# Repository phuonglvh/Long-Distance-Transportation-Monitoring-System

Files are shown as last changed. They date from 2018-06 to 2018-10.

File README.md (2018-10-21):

# **Long-Distance-Transportation-Monitoring-System**
In this project, we did make a Tracker and a real system that has been on the markets. This tracker is specially designed for portable and low power so that it can get along with the carriers for a months.

## Description
This system is made up of 2 main parts, a web server and trackers. Web server is powered by SailsJS MVC and MySQL database to collect humidity, temperature and coordinates of trackers. It also provides web service to users to monitor their packages (containers, ...). Front-end is designed to monitor their package via grap, google maps and some warning protection.

## System model
<p align="center">
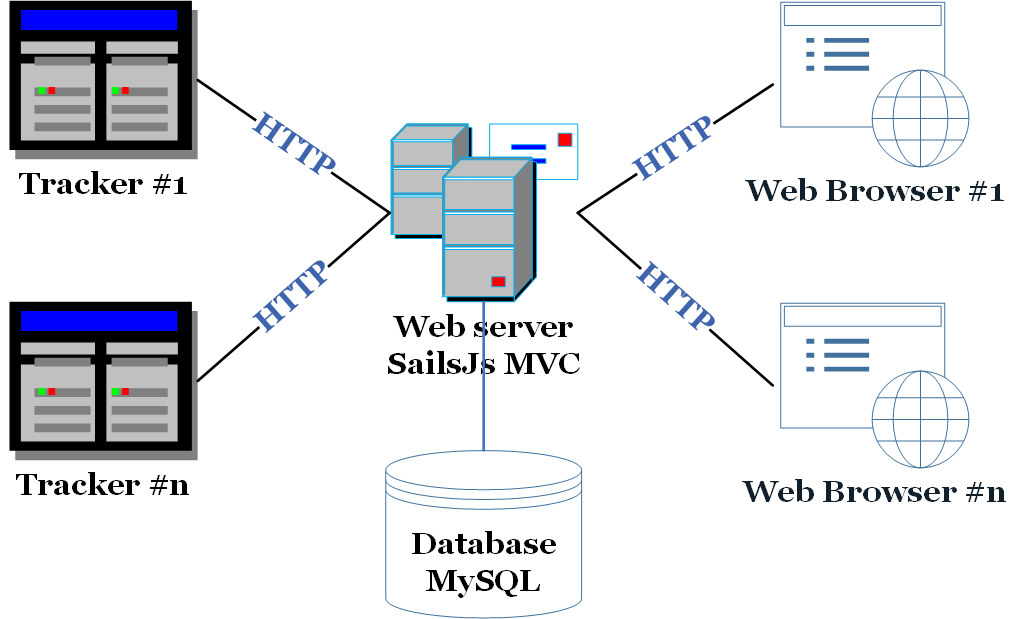
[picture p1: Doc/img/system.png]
System model
  
</p>

## Getting Started
These instructions will get you a copy of the project up and you can develop it for further purposes. See deployment for notes on how to deploy the project on a live system.

### Prerequisites
What things you need to have before operating the whole system
```
A server powered by Linux can run nodejs environment.
MySQL is installed on that server.
SailsJs application
```

### Installing
What you need to install
```
Ubuntu 16.04 or higher or other Linux Distros
nodejs: https://nodejs.org/en/
Sailsjs: https://sailsjs.com/get-started
mysql (I use Ubuntu): sudo apt-get install mysql-server mysql-client
```	

## Hierachy of Project
There are four main folder in this project:  **Web Server**,  **Tracker**,  **Doc**.

**Document** contains such files as *.pdf*, *.docx*, etc describing the whole of our project.
**Web Server** stores code that executed on a Linux Distro based PC.
**Tracker** contains code run on MC60 Kit.

## Deployment
At first, you should setup config/local.js. Add your MySQL information in it.
Secondly, navigate to Web Server root folder and hit ```./start.sh```.
Finally, power on your Kit

## Some results
<p align="center">
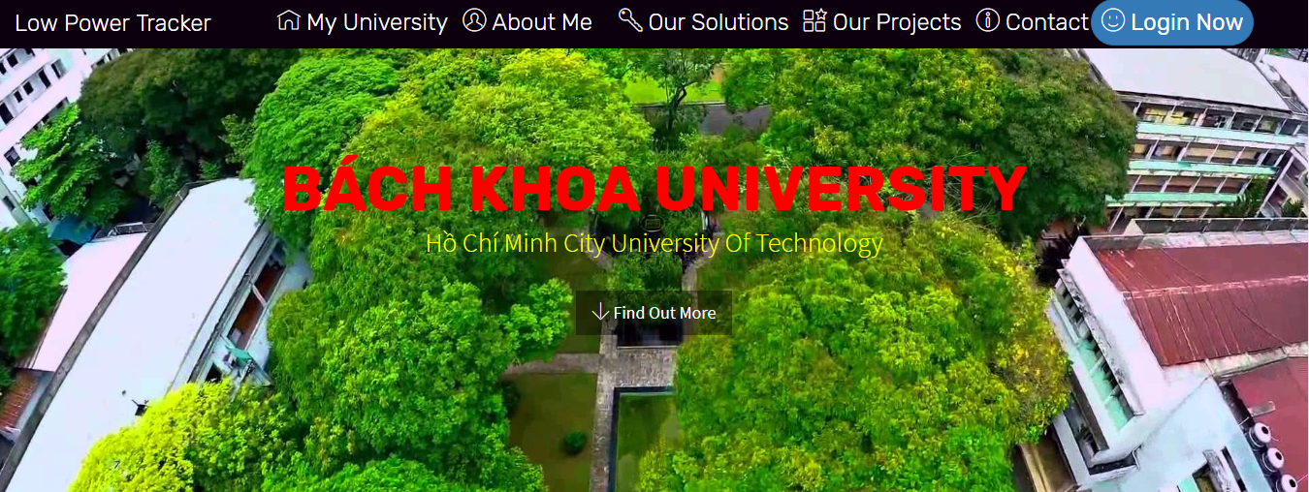
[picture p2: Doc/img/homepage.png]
homepage
  
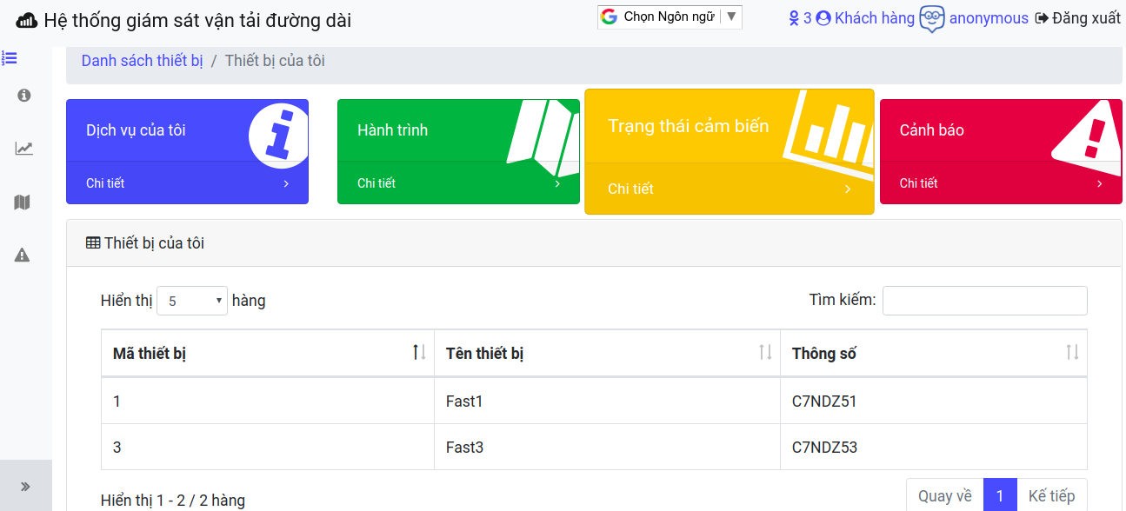
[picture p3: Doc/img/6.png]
Dashboard
  
</p>

<p align="center">
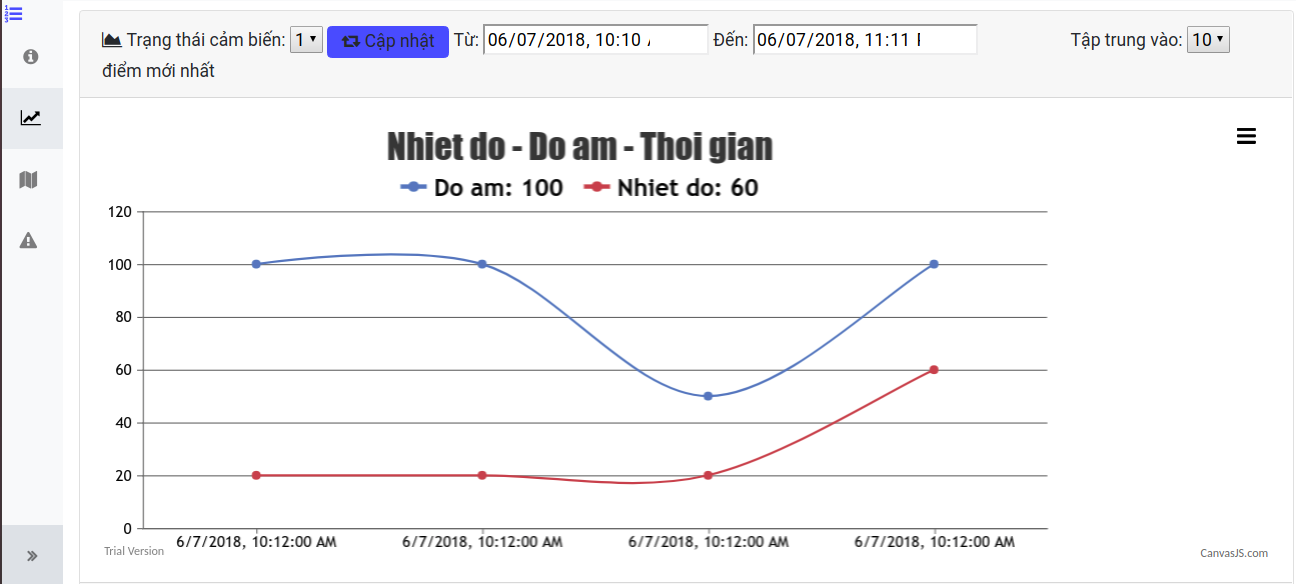
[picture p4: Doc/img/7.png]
Graph
  
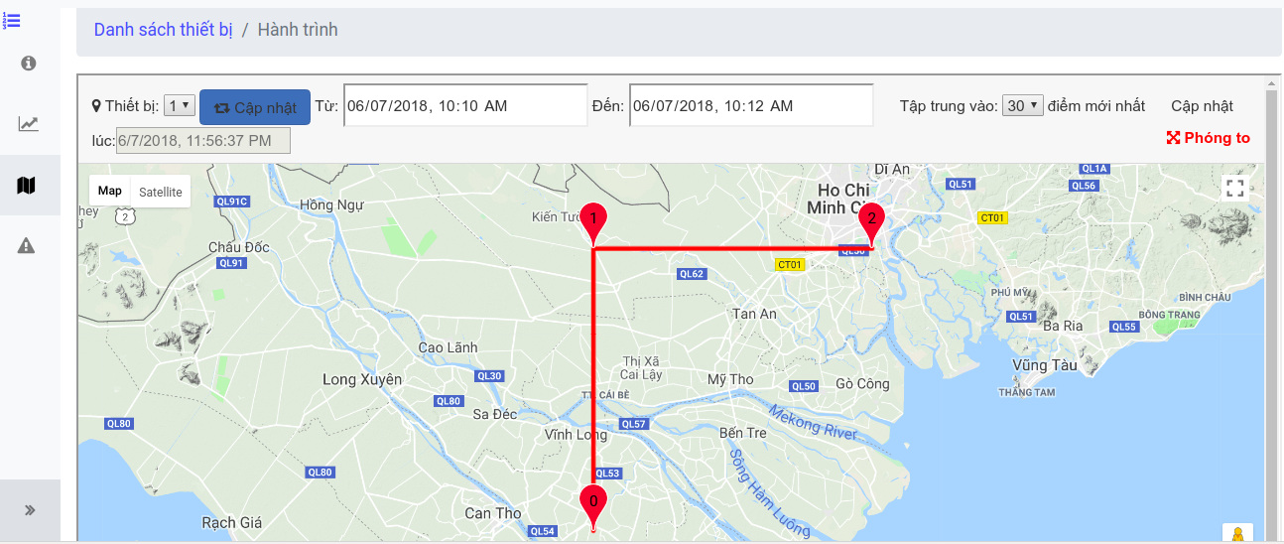
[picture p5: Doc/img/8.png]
Map
  
</p>

<p align="center">
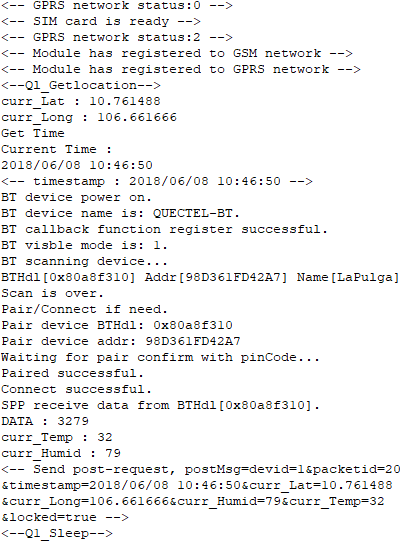
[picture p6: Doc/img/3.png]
MC60
  
</p>

<p align="center">
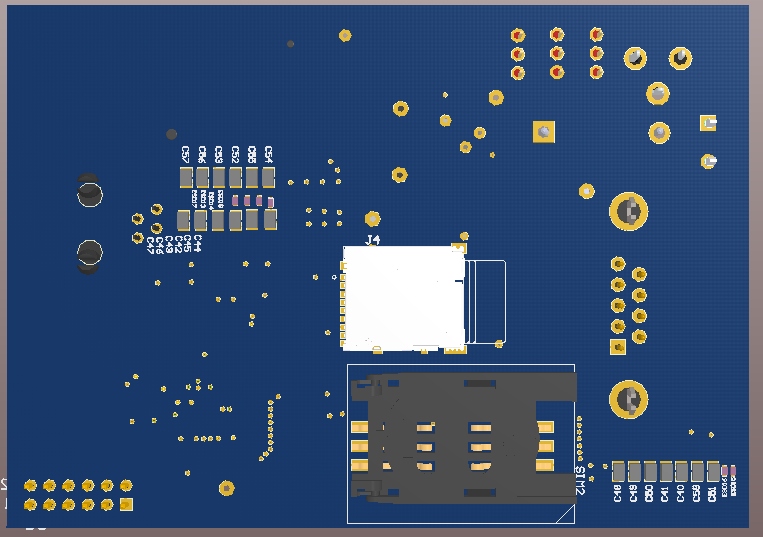
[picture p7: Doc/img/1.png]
top
  
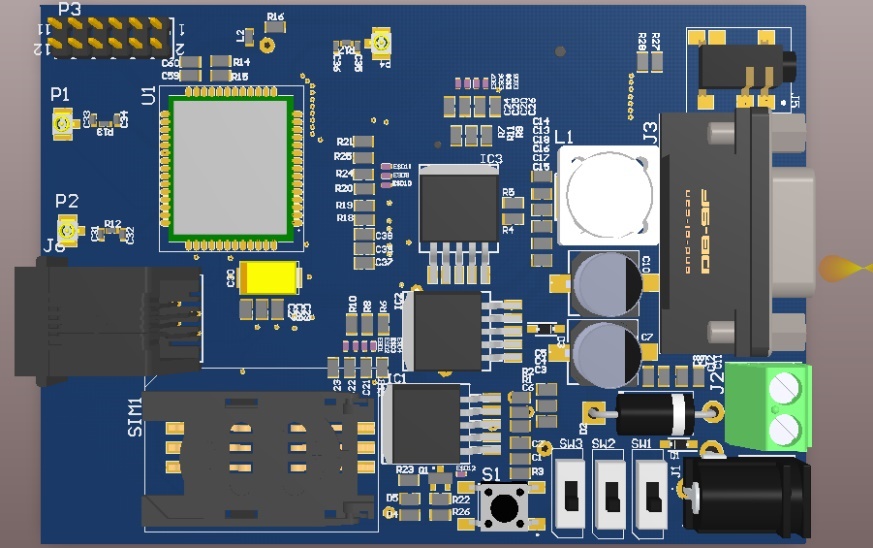
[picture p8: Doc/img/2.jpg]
bottom
  
</p>

## Team members

* **Phuong Le Van Hoang** - **Leader**, *Operating Platform Development*, *Web Server*
* **Nhan Huu Nguyen** - *Firmware Development*
* **Hieu Trung Nguyen** - *Hardware Design*

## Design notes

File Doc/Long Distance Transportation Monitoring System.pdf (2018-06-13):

### ĐẠI HỌC QUỐC GIA TP.HỒ CHÍ MINH TRƯỜNG ĐẠI HỌC BÁCH KHOA KHOA ĐIỆN – ĐIỆN TỬ BỘ MÔN ĐIỆN TỬ

-------------o0o-------------

## ĐỒ ÁN MÔN HỌC

## HỆ THỐNG GIÁM SÁT VẬN TẢI ĐƯỜNG DÀI

GVHD: TS. Trương Quang Vinh
SVTH | MSSV
Lê Văn Hoàng Phương 1512579
Nguyễn Hữu Nhân | 1512263
Nguyễn Trung Hiếu | 1511027

TP. HỒ CHÍ MINH, THÁNG 6 NĂM 2018

Lời cảm ơn | GVHD: TS. Trương Quang Vinh

i

## LỜI CẢM ƠN

Lời đầu tiên, chúng em xin gửi lời cảm ơn tới tiến sĩ Trương Quang Vinh đã quan tâm, hướng

dẫn, cung cấp thông tin và giúp nhóm em trong quá trình hoàn thành đồ án này. Hơn nữa em

xin cảm ơn tất cả thầy cô trường Đại học Bách Khoa TP Hồ Chí Minh đã giúp đỡ, truyền đạt

những kiến thức chuyên ngành quý giá giúp em hoàn thành đồ án này. Và cuối cùng, em xin

chân thành cảm ơn gia đình và bạn bè đã động viên khích lệ nhóm em trong quá trình học tập và hoàn thành đồ án.

Do thời gian thực hiện không nhiều nên đồ án không tránh khỏi những sai sót. Em rất mong

nhận được lời khuyên và sự đóng góp ý kiến của các thầy cô giáo và các bạn quan tâm đến đề

tài này để em có thể bổ sung và tiếp tục phát triển đề tài trong thời gian tới.

Em xin chân thành cảm ơn!

Tp. Hồ Chí Minh, ngày 6 tháng 6 năm 2018.

Sinh viên

Đồ án môn học | GVHD: TS. Trương Quang Vinh

ii

## TÓM TẮT ĐỒ ÁN

Đồ án này trình bày về thiết kế hệ thống giám sát vận tải đường dài. Đề tài chủ yếu tập trung vào

thiết kế sơ bộ một hệ thống gồm 2 thành phần quan trọng là máy chủ dịch vụ web và thiết bị thu

thập dữ liệu, đề xuất giải pháp tối ưu phần cứng. Dịch vụ web được thiết kế theo mô hình MVC với

framework chính là SailsJS, một framework được xây dựng trên nền tảng nodejs và được tính hợp

rất nhiều tính năng tiện lợi. Phần cứng là thiết bị thu thập nhiệt độ, độ ẩm, trạng khái khóa, GPS mà

trung tâm điều khiển là Quectel MC60, với giá thành vừa phải, đủ ngoại vi cần thiết và đầy đủ giao

thức mạng. Phần cứng được thiết kế và lập trình tối ưu nhằm tăng hiệu xuất và tiết kiệm năng lượng.

Giao tiếp người dùng (GUI) được xây dựng chính trên nền tảng web để người dùng có thể giám sát

gói hàng, thiết bị vận tải của mình một cách dễ dàng.

iii

## MỤC LỤC

1. GIỚI THIỆU _________________________________________________________________________________________________________ 1
1.1. Tổng quan ____________________________________________________________________________________________________ 1
1.1.1. Tình hình nghiên cứu trong nước___________________________________________________________________ 1
1.1.2. Tình hình nghiên cứu ngoài nước __________________________________________________________________ 1
1.2. Nhiệm vụ đề tài ______________________________________________________________________________________________ 2
1.3. Phân chia công việc trong nhóm __________________________________________________________________________ 3
2. LÝ THUYẾT _________________________________________________________________________________________________________ 4
2.1. Công nghệ GPS _______________________________________________________________________________________________ 4
2.2. Công nghệ Bluetooth ________________________________________________________________________________________ 4
2.3. Dịch vụ GPRS _________________________________________________________________________________________________ 4
3. TỔNG QUÁT HỆ THỐNG___________________________________________________________________________________________ 5
3.1. Mô tả hệ thống _______________________________________________________________________________________________ 5
4. THIẾT KẾ VÀ THỰC HIỆN PHẦN CỨNG _________________________________________________________________________ 7
4.1. Yêu cầu thiết kế ______________________________________________________________________________________________ 7
4.2. Phân tích thiết kế ____________________________________________________________________________________________ 7
4.3. Sơ đồ khối tổng quát ________________________________________________________________________________________ 8
4.3.1. MC60_____________________________________________________________________________________________________ 8
4.3.2. Khối cấp nguồn_________________________________________________________________________________________ 9
4.3.3. Khối giao tiếp Audio__________________________________________________________________________________10
4.3.4. Khối Giao tiếp thẻ SIM _______________________________________________________________________________11
4.3.5. Khối Antenna__________________________________________________________________________________________11
4.3.6. Khối giao tiếp UART__________________________________________________________________________________12
4.3.7. Giao tiếp với thẻ SD __________________________________________________________________________________12
4.3.8. POWER LED và NETLIGHT LED ____________________________________________________________________13
4.3.9. Nút nhấn PWRKEY____________________________________________________________________________________13
4.3.10. Khối cảm biến _________________________________________________________________________________________14
4.4. Tính toán và vẽ sơ đồ mạch chi tiết______________________________________________________________________17
4.4.1. MC60-OpenCPU _______________________________________________________________________________________17

iv

4.4.2. Khối cấp nguồn________________________________________________________________________________________18
4.4.3. Khối giao tiếp Audio__________________________________________________________________________________21
4.4.4. Khối giao tiếp thẻ SIM________________________________________________________________________________22
4.4.5. Khối antenna __________________________________________________________________________________________23
4.4.6. Giao tiếp UART ________________________________________________________________________________________27
4.4.7. Giao tiếp với thẻ SD __________________________________________________________________________________28
4.4.8. POWER LED và NETLIGHT LED, PWRKEY Button_______________________________________________29
5. THIẾT KẾ VÀ THỰC HIỆN PHẦN MỀM _________________________________________________________________________31
5.1. Phần mềm thiết bị giám sát (Tracker) __________________________________________________________________31
5.1.1. Phân tích _______________________________________________________________________________________________31
5.1.2. Yêu cầu đặt ra cho phần mềm_______________________________________________________________________31
5.1.3. Cấu trúc chương trình _______________________________________________________________________________32
5.1.4. Lưu đồ giải thuật tổng quát _________________________________________________________________________32
5.1.5. Lưu đồ giải thuật chi tiết ____________________________________________________________________________33
5.2. Phần mềm web server _____________________________________________________________________________________38
5.2.1. Yêu cầu đặt ra _________________________________________________________________________________________38
5.2.2. Phân tích _______________________________________________________________________________________________38
5.2.3. Thiết kế web server __________________________________________________________________________________39
6. KẾT QUẢ THỰC HIỆN ____________________________________________________________________________________________44
6.1. Phần cứng ___________________________________________________________________________________________________44
6.1.1. 3D _______________________________________________________________________________________________________44
6.1.2. LAYOUT ________________________________________________________________________________________________45
6.2. Thiết bị giám sát ____________________________________________________________________________________________46
6.2.1. Thử nghiệm phần mềm giám sát trên KIT MC60 và KIT TM4C123GH6PM __________________46
6.3. Máy chủ dịch vụ web _______________________________________________________________________________________51
6.3.1. Frontend _______________________________________________________________________________________________51
6.4. Đánh giá kết quả____________________________________________________________________________________________57
6.4.1. Phần cứng______________________________________________________________________________________________57
6.4.2. Đánh giá tổng quát kết quả phần cứng ____________________________________________________________59

v

6.4.3. Thiết bị giám sát ______________________________________________________________________________________59
6.4.4. Máy chủ web___________________________________________________________________________________________59
6.4.5. Làm việc nhóm ________________________________________________________________________________________60
7. KẾT LUẬN VÀ HƯỚNG PHÁT TRIỂN ___________________________________________________________________________61
7.1. Kết luận ______________________________________________________________________________________________________61
7.2. Hướng phát triển ___________________________________________________________________________________________61
8. TÀI LIỆU THAM KHẢO ___________________________________________________________________________________________62
9. PHỤ LỤC____________________________________________________________________________________________________________63
9.1. Code web server và thiết bị giám sát ____________________________________________________________________63
9.2. Danh sách linh kiện trong bản vẽ ________________________________________________________________________63

vi

## DANH SÁCH HÌNH MINH HỌA

HÌNH 3.1.1 SƠ ĐỒ KHỐI TỔNG QUÁT HỆ THỐNG ___________________________________________________________________ 5

HÌNH 3.1.2 SƠ ĐỒ KHỐI THIẾT BỊ GIÁM SÁT ________________________________________________________________________ 6 HÌNH 4.3.1 SƠ ĐỒ KHỐI TỔNG QUÁT PHẦN CỨNG _________________________________________________________________ 8

HÌNH 4.3.2 VI ĐIỀU KHIỂN MC-60_____________________________________________________________________________________ 9

HÌNH 4.3.3 SƠ ĐỒ KHỐI CẤP NGUỒN _________________________________________________________________________________ 9

HÌNH 4.3.4 SƠ ĐỒ KHỐI AUDIO_______________________________________________________________________________________10

HÌNH 4.3.5 SƠ ĐỒ KHỐI EARPHONE _________________________________________________________________________________10

HÌNH 4.3.6 SƠ ĐỒ KHỐI MC60-EARPHONE _________________________________________________________________________11

HÌNH 4.3.7 SƠ ĐỒ KHỐI MC60 - SIM _________________________________________________________________________________11

HÌNH 4.3.8 SƠ ĐỒ KHỐI ANTENNA___________________________________________________________________________________11

HÌNH 4.3.9 SƠ ĐỒ KHỐI GIAO TIẾP UART __________________________________________________________________________12

HÌNH 4.3.10 SƠ ĐỒ KHỐI KẾT NỐI MAIN UART – DB9 ____________________________________________________________12

HÌNH 4.3.11 SƠ ĐỒ KHỐI GIAO TIẾP SD CARD _____________________________________________________________________12 HÌNH 4.3.12 THỜI GIAN BẬT MODULE BẰNG PWRKEY___________________________________________________________13

HÌNH 4.3.13 THỜI GIAN TẮT MODULE BẰNG PWRKEY___________________________________________________________14

HÌNH 4.3.14 SƠ ĐỒ KẾT NỐI KHỐI CẢM BIẾN ______________________________________________________________________14

HÌNH 4.3.15 KIT TM4C123 ____________________________________________________________________________________________15 HÌNH 4.3.16 SƠ ĐỒ CHÂN DHT11 ____________________________________________________________________________________16

HÌNH 4.3.17 SƠ ĐỒ CHÂN HC-05 _____________________________________________________________________________________16

HÌNH 4.4.1 SƠ ĐỒ CHÂN MC60 _______________________________________________________________________________________17

HÌNH 4.4.2 SƠ ĐỒ KẾT NỐI MC60 ____________________________________________________________________________________18

HÌNH 4.4.3 ĐẦU VÀO 5V SỬ DỤNG DC JACK 3 CHÂN_______________________________________________________________18

HÌNH 4.4.4 KHỐI CẤP NGUỒN_________________________________________________________________________________________19

HÌNH 4.4.5 LẤY ĐIỆN ÁP TỪ MIC29302 _____________________________________________________________________________19

HÌNH 4.4.6 SƠ ĐỒ VBAT _______________________________________________________________________________________________20

HÌNH 4.4.7 TÍNH ĐỘ RỘNG POWER TRACE _________________________________________________________________________21

HÌNH 4.4.8 MC60 - HANDSET QUA AUDIO CHANNEL 1____________________________________________________________21

HÌNH 4.4.9 MC60 – EARPHONE QUA AUDIO CHANNEL 2 _________________________________________________________22 HÌNH 4.4.10 SƠ ĐỒ MẠCH CHI TIẾT SIM1___________________________________________________________________________22

HÌNH 4.4.11 SƠ ĐỒ MẠCH CHI TIẾT SIM2___________________________________________________________________________23

HÌNH 4.4.12 SƠ ĐỒ MẠCH GSM ANTENNA __________________________________________________________________________24

HÌNH 4.4.13 SƠ ĐỒ MẠCH GNSS ANTENNA _________________________________________________________________________25

HÌNH 4.4.14 SƠ ĐỒ MẠCH GSM ANTENNA __________________________________________________________________________26

HÌNH 4.4.15 THIẾT KẾ RF TRACE 50Ω_______________________________________________________________________________27

HÌNH 4.4.16 SƠ ĐỒ MẠCH CHI TIẾT MAIN UART __________________________________________________________________27

HÌNH 4.4.17 SƠ ĐỒ CHÂN DB9________________________________________________________________________________________28

HÌNH 4.4.18 SƠ ĐỒ MẠCH SD CARD__________________________________________________________________________________29

vii

HÌNH 4.4.19 SƠ ĐỒ MẠCH POWER LED _____________________________________________________________________________29

HÌNH 4.4.20 SƠ ĐỒ MẠCH PWRKEY BUTTON ______________________________________________________________________30

HÌNH 5.1.1 CẤU TRÚC CHƯƠNG TRÌNH GIÁM SÁT RTOS MỘT TASK ___________________________________________32 HÌNH 5.1.2 GIẢI THUẬT TỔNG QUÁT CHƯƠNG TRÌNH GIÁM SÁT_______________________________________________32

HÌNH 5.1.3 GIẢI THUẬT BOOT SYSTEM _____________________________________________________________________________33

HÌNH 5.1.4 GIẢI THUẬT LOCATION PROGRAM_____________________________________________________________________33 HÌNH 5.1.5 GIẢI THUẬT ĐỌC CẢM BIẾN_____________________________________________________________________________34

HÌNH 5.1.6 GIẢI THUẬT TRUYỀN NHẬN BLUETOOTH(HOST) ___________________________________________________35

HÌNH 5.1.7 GIẢI THUẬT TRUYỀN NHẬN BLUETOOTH (SLAVE) __________________________________________________36

HÌNH 5.1.8 GIẢI THUẬT HTTP POST_________________________________________________________________________________37

HÌNH 5.2.1 MÔ HÌNH MVC VÀ SAILSJS _______________________________________________________________________________39 HÌNH 5.2.2 GIAO DIỆN TRANG CHỦ __________________________________________________________________________________40

HÌNH 5.2.3 GIAO DIỆN QUẢN LÍ CỦA KHÁCH HÀNG _______________________________________________________________40

HÌNH 5.2.4 GIAO DIỆN QUẢN LÍ CỦA QUẢN TRỊ VIÊN _____________________________________________________________40 HÌNH 5.2.5 CẤU TRÚC CSDL VÀ QUAN HỆ GIỮA CÁC TRƯỜNG __________________________________________________41

HÌNH 6.1.1 ẢNH 3D MẶT TRÊN _______________________________________________________________________________________44

HÌNH 6.1.2 ẢNH 3D MẶT DƯỚI CỦA MẠCH _________________________________________________________________________44 HÌNH 6.1.3 ẢNH LAYOUT PHẦN CỨNG ______________________________________________________________________________45

HÌNH 6.2.1 KẾT QUẢ DỮ LIỆU GPS ___________________________________________________________________________________46

HÌNH 6.2.2 KẾT QUẢ DỮ LIỆU THỜI GIAN __________________________________________________________________________46

HÌNH 6.2.3 KẾT QUẢ ĐỌC CẢM BIẾN NHIỆT ĐỘ - ĐỘ ẨM _________________________________________________________47

HÌNH 6.2.4 QUÁ TRÌNH GỬI DỮ LIỆU________________________________________________________________________________48

HÌNH 6.2.5 SERVER ĐÃ NHẬN DỮ LIỆU THÀNH CÔNG ____________________________________________________________48 HÌNH 6.2.6 SERVER TỪ CHỐI LƯU DỮ LIỆU DO PACKET ĐÃ NHẬN TRƯỚC ĐÓ_______________________________49

HÌNH 6.2.7 TRẠNG THÁI CẢM BIẾN TRƯỚC KHI WEB SERVER NHẬN DỮ LIỆU_______________________________49

HÌNH 6.2.8 TRẠNG THÁI CẢM BIẾN SAU KHI SERVER NHẬN DỮ LIỆU__________________________________________49

HÌNH 6.2.9 HÀNH TRÌNH TRƯỚC KHI SERVER NHẬN DỮ LIỆU__________________________________________________50

HÌNH 6.2.10 HÀNH TRÌNH SAU KHI SERVER NHẬN DỮ LIỆU ____________________________________________________50 HÌNH 6.3.1 KẾT QUẢ: TRANG CHỦ ___________________________________________________________________________________51

HÌNH 6.3.2 KẾT QUẢ: GIAO DIỆN QUẢN LÍ THÔNG TIN TÀI KHOẢN ____________________________________________51

HÌNH 6.3.3 KẾT QUẢ: GIAO DIỆN - QTV______________________________________________________________________________51

HÌNH 6.3.4 KẾT QUẢ: QUẢN LÍ DỊCH VỤ - QTV _____________________________________________________________________52

HÌNH 6.3.5 KẾT QUẢ: XEM LỊCH SỬ DV - QTV ______________________________________________________________________52

HÌNH 6.3.6 KẾT QUẢ: TRANG QUẢN LÍ - KH ________________________________________________________________________52

HÌNH 6.3.7 KẾT QUẢ: BẢNG THÔNG TIN DỊCH VỤ CỦA KH _______________________________________________________53

HÌNH 6.3.8 KẾT QUẢ: BẢNG TRẠNG THÁI CẢM BIẾN - KH ________________________________________________________53

HÌNH 6.3.9 KẾT QUẢ: GIÁM SÁT HÀNH TRÌNH - KH _______________________________________________________________53

HÌNH 6.3.10 KẾT QUẢ: NGƯỠNG - KH _______________________________________________________________________________54

HÌNH 6.3.11 GIAO DIỆN CẢNH BÁO -KH _____________________________________________________________________________54

viii

HÌNH 6.3.12 GIAO DIỆN QUẢN LÍ THIẾT VỊ - QTV__________________________________________________________________54

HÌNH 6.3.13 MÀN HÌNH CONSOLE MÁY CHỦ________________________________________________________________________55

HÌNH 6.3.14 THÔNG TIN TRÊN MYSQL ______________________________________________________________________________55 HÌNH 6.3.15 MÔ PHỎNG GỬI DỮ LIỆU SỬ DỤNG POSTMAN APP________________________________________________56 HÌNH 6.3.16 YÊU CẦU TỪ POSTMAN ĐƯỢC GHI LẠI TRÊN CONSOLE___________________________________________56

HÌNH 6.4.1 KHỐI NGUỒN (TOP) ______________________________________________________________________________________57

HÌNH 6.4.2 KHỐI NGUỒN (BOTTOM) ________________________________________________________________________________57

HÌNH 6.4.3 KHỐI ANTENNA(TOP)____________________________________________________________________________________58

HÌNH 6.4.4 KHỐI ANTENNA(BOTTOM)______________________________________________________________________________58

HÌNH 6.4.5 ĐƯỜNG DÂY TRUYỀN SÓNG_____________________________________________________________________________58

ix

## DANH SÁCH BẢNG SỐ LIỆU

BẢNG 1.3.1 PHÂN CHIA CÔNG VIỆC TRONG NHÓM _________________________________________________________________ 3

BẢNG 4.2.1 LỰA CHỌN MCU____________________________________________________________________________________________ 7

BẢNG 4.2.2 LỰA CHỌN ANTENNA _____________________________________________________________________________________ 7 BẢNG 4.3.1 CHỨC NĂNG CÁC KHỐI PHẦN CỨNG____________________________________________________________________ 8

BẢNG 4.4.1 MÔ TẢ CHÂN AUDIO CHANNEL 1_______________________________________________________________________21

BẢNG 4.4.2 MÔ TẢ CHÂN AUDIO JACK_______________________________________________________________________________22

BẢNG 4.4.3 MÔ TẢ CHÂN SIM1 _______________________________________________________________________________________23

BẢNG 4.4.4 MÔ TẢ CHÂN SIM2 _______________________________________________________________________________________23 BẢNG 4.4.5 YÊU CẦU ANTENNA CABLE ______________________________________________________________________________24

BẢNG 4.4.6 YÊU CẦU THÔNG SỐ ANTENNA _________________________________________________________________________24

BẢNG 4.4.7 CÁC DẢI TẦN GSM ________________________________________________________________________________________25

BẢNG 4.4.8 THÔNG SỐ ĐỐI VỚI ANTENNA GPS ____________________________________________________________________25

BẢNG 4.4.9 MÔ TẢ CHÂN CỦA CỔNG DB9 ___________________________________________________________________________28

BẢNG 4.4.10 MÔ TẢ CHÂN CỦA MICRO-SD__________________________________________________________________________29

BẢNG 5.2.1 TÍNH NĂNG CỦA GIAO DIỆN WEB ______________________________________________________________________38 BẢNG 5.2.2 TÍNH NĂNG GIAO TIẾP VỚI TRACKER_________________________________________________________________38

BẢNG 5.2.3 API PHỤC VỤ DỊCH VỤ WEB_____________________________________________________________________________41 BẢNG 5.2.4 API PHỤC VỤ GIAO TIẾP TRACKER ____________________________________________________________________43

BẢNG 5.2.5 CẤU TRÚC GÓI DỮ LIỆU TRACKER GỬI ĐẾN SERVER _______________________________________________43

BẢNG 5.2.6 CẤU TRÚC GÓI JSON SERVER TRẢ LỜI TRACKER NẾU NHẬN THÀNH CÔNG_____________________43 BẢNG 6.2.1 GPS MẪU___________________________________________________________________________________________________46

x

## THUẬT NGỮ/VIẾT TẮT TIẾNG ANH/VIỆT

[1] Web server: máy chủ lưu trữ dữ liệu và cung cấp dịch vụ web.
[2] Tracker: thiết bị giám sát/thiết bị thu thập dữ liệu.
[3] GUI: graphic user interface
[4] Font-end: giao diện người dùng
[5] Back-end: chương trình chạy tại server
[6] API: application programming interface
[7] MC60: Quectel MC60 Ultra-small LCC Quad-band GSM/GPRS/GNSS Module
[8] RTOS: Realtime Operating System
[9] QTV: quản trị viên
[10] KH: khách hàng

1

### 1. GIỚI THIỆU

### 1.1. Tổng quan

Thế kỉ 21 đánh dấu sự phát triển vượt bật của ngành điện tử, bên cạnh các lĩnh vực công nghệ

cao như IC, RFIC, … thì IoT hiện nay trở thành một xu hướng của thế giới.

Sự phát triển của ngành giao thông vận tải và các ngành kinh tế khác liên quan đã đặt ra một

dấu chấm hỏi mới cho lĩnh vực IoT. Vì sao lại như vậy? Khác với ngành vận tải truyền thống,

ngày nay chúng ta đòi hỏi nghiêm ngặt hơn trong việc giám sát hàng hóa của mình. Hơn thế

nữa, việc vận chuyển hàng hóa có thể vượt không gian, thời gian, châu lục, vậy thì việc đảm

bảo chắc chắn rằng hàng hóa của tôi chất lượng còn nguyên vẹn và dịch vụ vẩn chuyển của tôi

là tốt thì việc đòi hỏi các thiết bị hỗ trợ là môt tất yếu. Chính vì lẽ đó mà có lẽ đã từ rất lâu thiết

bị giám sát đã ra đời đóng góp không nhỏ trong việc phát triển thương mại, giao thông vận tải.

Vì thế không khó hiểu khi những thiết bị giám sát như thế đang ngày càng được cải thiện và

nâng cao chất lượng.

### 1.1.1. Tình hình nghiên cứu trong nước

Hiện nay có rất nhiều doanh nghiệp trong nước cho ra đời thiết bị giám sát hành trình, nhiệt độ,

độ ẩm, … Vậy đâu là dòng sản phẩm tốt nhất, hiệu quả nhất, kinh thế và bền bỉ nhất? Đây có lẽ

là một bài toán không có câu trả lời vì công nghệ không có giới hạn.

Các sản phẩm trong nước thường có những tính năng như sau:

- Định vị vị trí
- Giám sát nhiệt độ, độ ẩm
- Bảo vệ khóa
- Chống nước, chống sốc

Tuy nhiên, đa số các sản phẩm thường sử dụng nguồn điện rời, nguồn điện trực tiếp từ động cơ

hoặc nguồn điện sử dụng được trong thời gian ngắn khiến cho sản phẩm còn một số hạn chế

như: không tách rời, vận tải trong thời gian không dài, …

### 1.1.2. Tình hình nghiên cứu ngoài nước

Hiện nay thị trường nước ngoài đã có những sản phẩm rất tuyệt vời, đáp ứng được những khuyết

điểm trên. Tuy nhiên nếu xét khách hàng trong nước, thì những thiết bị như thế có giá rất cao,

dẫn đến là không phải doanh nghiệp hoặc cá nhân nào cũng mua được. Và sẽ như thế nào nếu

như sản phẩm của tôi bị hỏng?

2

### 1.2. Nhiệm vụ đề tài

Sau khi phân tích tình hình nghiên cứu trong và ngoài nước, cũng như thị trường tiêu thụ, nhóm chúng tôi đã đề xuất xây dựng một hệ thống giám sát vận tải đường dài kế thừa đầy đủ các tính

năng cơ bản, nhưng được cải thiện đáng kể chính là: tiết kiệm năng lượng, thời gian sử dụng

lâu cho vận tải đường dài, thiết bị được đóng gói rời, có thể gắn trên gói hàng hóa để đi theo

suốt hành trình mà không phụ thuộc vào phương tiện vận chuyển.

Từ ý tưởng trên, trong đồ án này, chúng tôi cơ bản tiến hành nghiên cứu với những nội dung

sau:

Nội dung 1: Tìm hiểu về framework SailsJs, MVC và MySQL.

Nội dung 2: Thiết kế website dựa trên nền tảng SailsJS. Giao diện thiết kế cho 2 đối tượng:

khách hàng và quản trị viên. Khách hàng có thể quản lí thông tin tài khoản của mình, quản lí

thiết bị đã đăng kí, theo dõi nhiệt độ - độ ẩm qua biểu đồ và định vị trên Google Map, cảnh báo

vượt ngưỡng và mở khóa. Quản trị viên chính là nhà cung cấp dịch vụ (cung cấp thiết bị giám

sát), có thể quản lí được tài khoản khách hàng, quản lí các dịch vụ, xem lịch sử dịch vụ và các

cài đặt liên quan. Thông tin hiển thị trên web có thể được cập nhật thủ công.

Nội dung 3: Tìm hiểu các module cần thiết để đảm bảo có đủ các chức năng: kết nối

GPRS/2G/3G, UART, Bluetooth, khối cấp nguồn, antenna. Nẵm vững kiến thức về phần cứng

đồng thời hiện thực hóa những module trên bằng schematic, layout.

Nội dung 4: Tìm hiểu và lập trình giao tiếp các ngoại vi như Bluetooth, GPS, GPIO và kết nối

mạng GPRS/2G/3G trên KIT MC60. Lập trình giao tiếp với cảm biến nhiệt độ, độ ẩm thông

qua Bluetooth. Hiểu về cấu trúc chương trình thực hiện trên Kit. Gửi được dữ liệu cơ bản gồm

nhiệt độ, độ ẩm, kinh độ, vĩ độ, thời gian, trạng thái khóa đến server.

Nội dung 5: Kết hợp phần mềm giám sát và phần mềm web server để thành một hệ thống hoàn

chỉnh, chạy thử và kiểm tra hệ thống.

3

### 1.3. Phân chia công việc trong nhóm

Bảng 1.3.1 Phân chia công việc trong nhóm

Thành viên | Vai trò | Công việc | Chi tiết công việc
Lê Văn Hoàng Phương | Nhóm trưởng | Web server | -Tìm hiểu về web, SailsJs, framework - Thiết kế giao diện web(frontend) - Thiết kế backend web - Xây dựng web theo mô hình MVC - Giao tiếp giữa server và thiết bị giám sát
Nguyễn Hữu Nhân | Thành viên | Lập trình nhúng | - Tìm hiểu sử dùng Module SIM, AT command - Tìm hiểu giao thức mạng HTTP POST, GET - Tìm hiểu KIT MC60 - Giao tiếp ngoại vị MC60: GPS, Bluetooth - Kết nối đến Web server sử dụng MC60 - Gửi dữ liệu đến web server
Nguyễn Trung Hiếu | Thành viên | Thiết kế phần cứng | - Đề xuất mô hình phần cứng - Tìm hiểu các loại linh kiện và thị trường - Tối ưu phần cứng - Vẽ schematic phần cứng - Vẽ layout phần cứng - Thiết kế đường dây truyền sóng cho antenna

4

### 2. LÝ THUYẾT

### 2.1. Công nghệ GPS

- Hệ thống GPS (Global Positioning System) là hệ thống xác định vị trí toàn cầu dựa trên hệ

thống vệ tinh. GPS sẽ cung cấp thông tin vị trí địa lý và thời gian (UTC) tới tất cả các thiết

bị bắt GPS.

- Module GPS hỗ trợ gói tin chuẩn NMEA. Mặc định module sẽ trả về lần lượt 6 gói tin:

GPRMC, GPVTG, GPGGA, GPGSA, GPGSV, GPGLL với mục đích khác nhau. Tuy nhiên chỉ với gói tin GPRMC đã có đầy đủ thông tin cho ứng dụng. Ta chỉ cần cắt thông tin về

UTC time, latitude, longtitude và date.

### 2.2. Công nghệ Bluetooth

- Bluetooth là một tiêu chuẩn công nghệ không dây mở độc quyền để trao đổi dữ liệu trong

khoảng cách ngắn (sử dụng sóng vô tuyến bước sóng ngắn trong băng tần ISM từ 2400-

2480MHz) từ các thiết bị cố định và di động, tạo mạng lưới khu vực cá nhân với mức độ

bảo mật cao. Bluetooth đã được chuẩn hóa như IEEE802.15.1.

- Bluetooth có thể đạt được tốc độ truyền dữ liệu 1Mb/s. Bluetooth hỗ trợ tốc độ truyền tải

dữ liệu lên tới 720 Kbps trong phạm vi 10 m–100 m. Khác với kết nối hồng ngoại (IrDA),

kết nối Bluetooth là vô hướng và sử dụng giải tần 2,4 GHz.

### 2.3. Dịch vụ GPRS

- GPRS - General Packet Radio Service là một dịch vụ dữ liệu di động truy cập đến GSM

và IS-136 điện thoại người dùng di động.
- GPRS thay thế cho các kết nối có dây, như hệ thống này đã đơn giản hóa truy cập vào các

mạng dữ liệu gói tin như internet. Các nguyên tắc vô tuyến gói tin được sử dụng bởi GPRS

để vận chuyển các gói dữ liệu một cách cấu trúc giữa trạm di động GSM và mạng dữ liệu

gói bên ngoài. Các gói này có thể được chuyển trực tiếp đến các mạng chuyển mạch gói từ

các trạm di động GPRS.

5

### 3. TỔNG QUÁT HỆ THỐNG

### 3.1. Mô tả hệ thống

Hệ thống giám sát vận tải đường dài thực hiện chức năng là giám sát nhiệt độ - độ ẩm, trạng

thái khóa, hành trình thông qua môi trường GSM. Thiết bị giám sát (Tracker) được gắn xuyên

suốt theo thùng hàng/gói hàng vận chuyển, thường xuyên gửi dữ liệu nhiệt độ, độ ẩm, vị trí,

trạng thái khóa đến một máy chủ (Web Server). Người dùng, người đang thuê thiết bị giám sát

này có thể giám sát thùng hàng/gói hàng của mình đang vận chuyển thông qua trình duyệt web

(Web browser) trên máy tính hoặc điện thoai của họ. Người dùng có thể xem nhiệt độ, độ ẩm

thông qua biểu đồ, hành trình của thùng hàng thông qua bản đồ google map. Chức năng cài đặt

ngưỡng nhiệt độ, độ ẩm và cảnh báo được xây dựng nhằm hỗ trợ người dùng kiểm tra cửa đang

mở hay không, nhiệt độ, độ ẩm có nằm trong giới hạn an toàn hay không.

Để thực hiện được những chức năng trên, hệ thống được thiết kế tương ứng với 3 thành phần

chính được thể hiện thông qua hình dưới đây:

Hình 3.1.1 Sơ đồ khối tổng quát hệ thống

- Web server:
- Cung cấp dịch vụ giám sát thông qua website
- Xử lí dữ liệu nhận được từ tracker, lưu vào CSDL và cung cấp dữ liệu cho giao diện ở

người dùng

- Sử dụng mô hình MVC để quản lí xuyên suốt từ CSDL cho đến giao diện

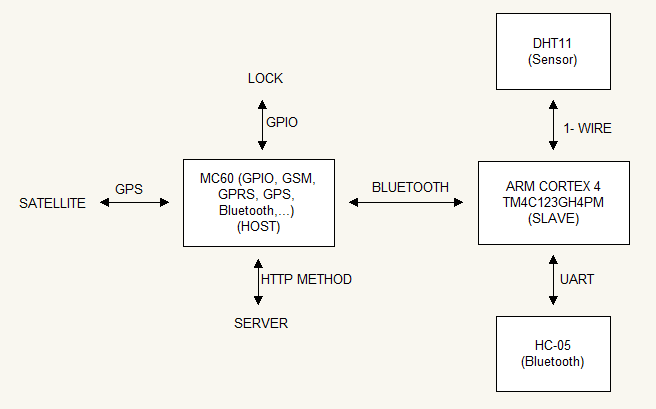
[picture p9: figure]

6

- Tracker (thiết bị giám sát): được gắn trên phương tiện vận tải hàng hóa, gửi dữ liệu nhiệt

độ, độ ẩm, GPS, thời gian, khóa đến máy chủ

Hình 3.1.2 Sơ đồ khối thiết bị giám sát

- Trình duyệt web (Web Browser): hiển thị giao diện web cho người dùng giám sát và quản

lí với các tính năng nêu trên

7

### 4. THIẾT KẾ VÀ THỰC HIỆN PHẦN CỨNG

### 4.1. Yêu cầu thiết kế

- Kích thước nhỏ gọn: 7x10 cm
- Giá thành hợp lý: 1 triệu đồng
- Giảm thiểu tối đa hao phí năng lượng
- Thực hiện truyền nhận đầy đủ các tín hiệu: GSM, GNSS, Bluetooth
- Các tín hiệu truyền tốt, không bị phản xạ, không nhiễu qua lại
- Giao tiếp UART để cập nhật firmware, nạp chương trình.
- Các linh kiện trong mạch cần được bảo vệ khỏi hiện tượng ESD để đảm bảo không bị hư

hại trong quá trình sử dụng, có thể hoạt động lâu dài.

### 4.2. Phân tích thiết kế

Từ yêu cầu đặt ra về mạch điện, các phương pháp được đề ra cho thiết kế như sau:

- MCU dùng để lập trình:

Bảng 4.2.1 Lựa chọn MCU

| STM32F103 | M60 Quectel
Giá thành | Rẻ (79,000 VNĐ) | Đắt (€16,40 = 436,232 VNĐ)
Truyền nhận GSM, GNSS, Bluetooth | Không tích hợp, cần sử dụng module hỗ trợ | Tích hợp cả 3 tính năng
- Ở đây ta chọn MCU là MC66 vì tích hợp cả GSM, GNSS và bluetooth
- Antenna:

Bảng 4.2.2 Lựa chọn Antenna

| Module chip antenna | PCB antenna | External antenna
Độ chính xác | Cao | Cao | Khá cao
Lắp đặt | Trung bình | Cần có chuyên môn để thiết kế chính xác | Đơn giản
Khả năng thay thế | Phức tạp | Không | Đơn giản

Qua thời gian sử dụng lâu dài, không thể tránh khỏi việc antenna bị hư hại, nên ở đây ta sử dụng

external antenna để thuận tiện cho việc thay thế, sửa chữa. Ngoài ra, external antenna còn thích

hợp cho việc lắp đặt antenna ở vị trí khác nhau trong các điều kiện khác nhau để nhận được

sóng tốt nhất.

8

### 4.3. Sơ đồ khối tổng quát

- Sơ đồ khối tổng quát:

Hình 4.3.1 Sơ đồ khối tổng quát phần cứng

- Chức năng của các khối:

Bảng 4.3.1 Chức năng các khối phần cứng

STT | Chức năng
1 | MC60 xử lý, điều khiển các hoạt động của module
2 | Giao tiếp, trao đổi dữ liệu với thẻ SIM
3 | Truyền nhận tín hiệu GPS, GNSS, Bluetooth
4 | Truyền dữ liệu nối tiếp, cập nhật software
5 | Giao tiếp, trao đổi dữ liệu với handset, earphone
6 | Giao tiếp, trao đổi dữ liệu với thẻ SD
7 | Báo trạng thái cấp nguồn cho GNSS (Power led) Báo trạng thái mạng (NETLIGHT led)
8 | Bật, tắt module bằng nút nhấn PWRKEY
9 | Cấp nguồn cho module
10 | Gồm cảm biến nhiệt độ, độ ẩm DHT11, Module Bluetooth HC05

### 4.3.1. MC60

- MC60 là module GSM/GPRS được tích hợp nhiều giao thức mạng như TCP, UDP, PPP,

FTP, HTTP và SSL, công nghệ định vị GNSS. Dựa trên Chipset 2G mới nhất. MC60 có

hiệu suất tối ưu trong tin nhắn SMS và truyền dữ liệu ngay cả trong môi trường khắc nghiệt

và và hỗ trợ chức năng Dual SIM Single Standby.

9

- MC60 tích hợp cả GNSS và GPRS trong một gói SMT nhỏ gọn. MC60 bổ sung hỗ trợ ở

hoạt động GLP (GNSS Low Power) đảm bảo độ chính xác cao trong khi tiêu thụ điện năng rất thấp và giao tiếp được với 2SIM.

Hình 4.3.2 Vi điều khiển MC-60

- Đặc điểm:
- Bang tần GSM: 850/900/1800/1900
- Đa giao thức internet: TCP, HTTP, UDP, FTP
- Hỗ trợ giao tiếp Bluetooth V3.0
- Giao tiếp được với 2 SIM
- Kênh thu GNSS, 99 kênh nhận, 33 kênh theo dõi
- Độ nhạy: -167dBm
- SMS, Call
- MC60 trong hệ thống này đảm nhiệm chức năng làm vi điều khiển trung tâm, điều khiển

thu nhận dữ liệu nhiệt độ, độ ẩm thông qua Bluetooth, nhận dữ liệu GPS từ module GPS,

giao tiếp với mạng GPRS để gửi dữ liệu đến web server thông qua giao thức HTTP POST.

### 4.3.2. Khối cấp nguồn

Hình 4.3.3 Sơ đồ khối cấp nguồn

- Module được cấp từ nguồn pin 24V DC hoặc nguồn 5V DC ( tại một thời điểm, chỉ có một

nguồn được sử dụng, chọn nguồn cấp bằng SW1)

- Nếu nguồn cấp là 24V sẽ đi qua bộ DC–DC giảm xuống còn 5V.
- Cho phép điện áp đi vào module bằng SW2.
- Điện áp 5V qua các bộ LDO (Low DropOut) thành các mức điện áp:

10

- 4V: Điện áp cung cấp cho hoạt động của khối GSM
- 3.3V: Điện áp cung cấp cho hoạt động của khối GNSS

### 4.3.3. Khối giao tiếp Audio

- Handset:

MC60 kit giao tiếp audio với handset bằng Audio Channel 1 thông qua cổng RJ11. Handset

dùng cho MC60 kit có sự khác biệt với Handset thông thường. Sơ đồ khối giao tiếp audio với

handset được mô tả như hình:

Hình 4.3.4 Sơ đồ khối Audio

- Earphone:

MC60 kit giao tiếp với earphone bằng Audio Channel 2. Đầu cắm earphone được sử dụng theo

chuẩn 2.5mm, 4 nấc, phác thảo như hình:

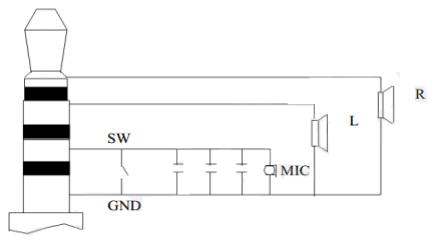
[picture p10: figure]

Hình 4.3.5 Sơ đồ khối Earphone

- Sơ đồ khối giao tiếp của MC60 kit với ear-phone:

11

Hình 4.3.6 Sơ đồ khối MC60-Earphone

### 4.3.4. Khối Giao tiếp thẻ SIM

MC60 kit hỗ trợ giao tiếp với 2 thẻ Sim. Cả hai giao tiếp với SIM1, SIM2 đều hỗ trợ thẻ SIM

1.8V hoặc 3.0V ( 1.8V, 3.0V là điện áp trên chân VCC của SIM khi hoạt động bình thường). Sơ đồ khối giao tiếp với thẻ SIM được mô tả như hình:

Hình 4.3.7 Sơ đồ khối MC60 - SIM

### 4.3.5. Khối Antenna

MC60 kit sử dụng SMT RF connector, có thể kết nối với antenna cách dễ dàng. Module sử dụng

3 antenna để truyền các tín hiệu GSM, GNSS và Bluetooth.

Hình 4.3.8 Sơ đồ khối antenna

12

### 4.3.6. Khối giao tiếp UART

Module ở đây sử dụng 3 port nối tiếp: UART Pỏrt, Auxiliary UART Port và GNSS UART Port.

Module được thiết kế như DCE ( Data Communication Equipment), theo kết nối DCE-DTE

(Data Terminal Equipment) truyền thống. Tốc độ baud hỗ trợ từ 4800bps đến 11520bps

- Main UART Port: Được sử dụng để cập nhật Firmware
- Auxiliary UART Port: Gửi, nhận data với phần GNSS
- GNSS UART Port: Gửi, nhận data với phần GSM.
- Sơ đồ khối:

Hình 4.3.9 Sơ đồ khối giao tiếp UART

- Main UART Port được kết nối thông qua cổng DB9:

Hình 4.3.10 Sơ đồ khối kết nối Main UART – DB9

### 4.3.7. Giao tiếp với thẻ SD

- Module cung cấp giao tiếp với thẻ SD để lưu trữ dữ liệu. Sơ đồ khối được thể hiện như hình:

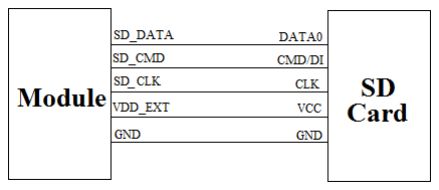
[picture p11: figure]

Hình 4.3.11 Sơ đồ khối giao tiếp SD Card

13

### 4.3.8. POWER LED và NETLIGHT LED

- POWER led: Sáng khi có nguồn 3.3V cấp cho hoạt động của khối GNSS.
- NETLIGHT LED: Hoạt động theo bảng trạng thái sau:

Bảng 4.3.2. Bảng trạng thái NETLIGHT LED

### 4.3.9. Nút nhấn PWRKEY

- Nút nhấn PWRKEY Được sử dụng để bật, tắt module.
- Để bật module, nhấn nút PWRKEY để tạo điện áp mức thấp vào chân PWRKEY của

module. Thời gian bật module được minh họa như hình dưới đây:

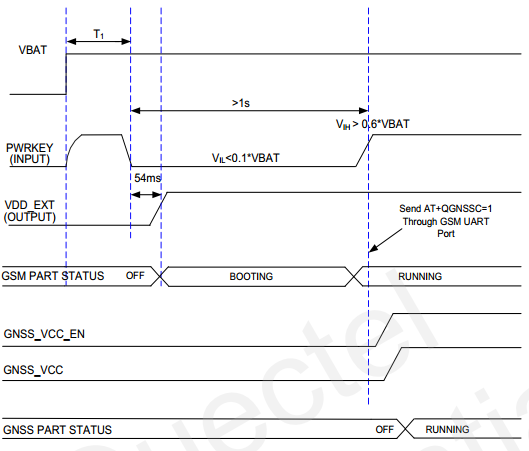
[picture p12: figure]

Hình 4.3.12 Thời gian bật module bằng PWRKEY

- Tương tự, để tắt module, nhấn nút PWRKEY để tạo điện áp mức thấp vào chân PWRKEY

của module. Thời gian tắt module được minh họa ở hình dưới đây:

14

Hình 4.3.13 Thời gian tắt module bằng PWRKEY

4.3.10.Khối cảm biến

Khối cảm biến gồm vi điều khiển TM4C123, cảm biến nhiệt độ, độ ẩm DHT11, module

Bluetooth HC-05. Trong bản thử nghiệm này, Kit TivaC TM4C123 được sử dụng để giao tiếp

với DHT11 đọc dữ liệu nhiệt độ, độ ẩm và giao tiếp với module Bluetooth HC-05 để gửi dữ

liệu đến vi điều khiển MC60.

### 4.3.10.1. Sơ đồ mạch khối cảm biến

Hình 4.3.14 Sơ đồ kết nối khối cảm biến

### 4.3.10.2. Kit TivaC TM4C123

- Vi điều khiển TM4C123 là vi điều khiển được thiết kế để phục vụ cho các ứng dụng công

nghiệp như giám sát từ xa, tự động hóa trong nhà máy, điều khiển chuyển động và các ứng

dụng mạng.

15

Hình 4.3.15 KIT TM4C123

- Đặc điểm:
- Vi xử lí: 32-bit ARM® Cortex™-M4 80-MHz
- Tích hợp: System Timer (SysTick), NVIC, WIC, Memory Protection Unit (MPU),

IEEE754-compliant single-precision Floating-Point Unit, System Control Block (SCB)

and Thumb-2 instruction set

- Flash (KB): 256
- RAM (KB): 32
- GPIO: 43
- I2C: 4
- ADC Channels: 12
- ADC Resolution (Bits): 12

### 4.3.10.3. Cảm biến nhiệt độ độ ẩm DHT11

- DHT11 là cảm biến nhiệt độ, độ ẩm rất thông dụng hiện nay vì chi phí rẻ và rất dễ lấy dữ

liệu thông qua giao tiếp 1-wire ( giao tiếp digital 1-wire truyền dữ liệu duy nhất). Cảm biến

được tích hợp bộ tiền xử lý tín hiệu giúp dữ liệu nhận về được chính xác mà không cần phải

qua bất kỳ tính toán nào

- Đặc điểm:
- Điện áp hoạt động : 3V - 5V (DC)
- Dải độ ẩm hoạt động : 20% - 90% RH, sai số ±5%RH
- Dải nhiệt độ hoạt động : 0°C ~ 50°C, sai số ±2°C
- Tần số lấy mẫu tối đa: 1 Hz
- Khoảng cách truyển tối đa: 20m

16

- Sơ đồ chân:

Hình 4.3.16 Sơ đồ chân DHT11

### 4.3.10.4. Module Bluetooth HC-05

Hình 4.3.17 Sơ đồ chân HC-05

- Mạch thu phát Bluetooth HC-05 đã ra chân được thiết kế nhỏ gọn ra chân tín hiệu giao tiếp

cơ bản và nút bấm để vào chế độ AT COMMAND, mạch được thiết kế để có thể cấp nguồn

và giao tiếp qua 3.3VDC hoặc 5VDC, thích hợp cho nhiều ứng dụng khác nhau: Robot

Bluetooth, điều khiển thiết bị qua Bluetooth,....

- Thông số kỹ thuật:
- Điện áp hoạt động: 3.3 ~ 5VDC
- Mức điện áp chân giao tiếp: TTL tương thích 3.3VDC và 5VDC
- Dòng điện khi hoạt động: khi Pairing 30 mA, sau khi pairing hoạt động truyền nhận bình

thường 8 mA
- Baudrate UART có thể chọn được: 1200, 2400, 4800, 9600, 19200, 38400, 57600,

115200
- Hỗ trợ mô hình: Bluetooth serial port (master and slave)
- Giao thức bluetooth: Bluetooth specification v2.0 + EDR
- Tần số: 2.4 GHz ISM band
- Điều chế: GFSK (Gaussian frequency shift keying)
- Công suất phát: =4 dBm, class 2
- Độ nhạy: =-84 dBm at 0.1% BER
- Tốc độ: Asynchronous: 2.1 Mbps (max.)/160 kbps
- Đồng bộ: 1 Mbps/1 Mbps

17

- Bảo mật: xác nhận và mã hóa
- Kích thước: 15.2 x 35.7 x 5.6mm

### 4.4. Tính toán và vẽ sơ đồ mạch chi tiết

### 4.4.1. MC60-OpenCPU

- Mô tả chức năng của MC60:

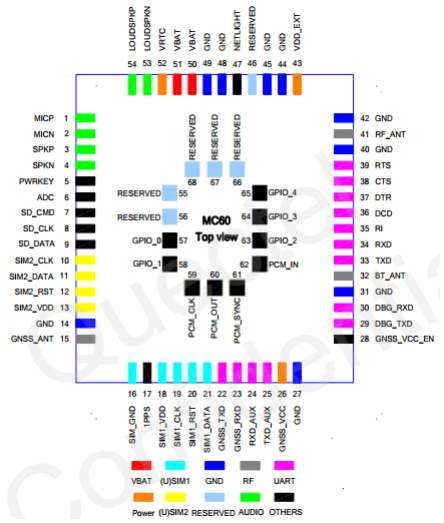
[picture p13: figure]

Hình 4.4.1 Sơ đồ chân MC60

- Sơ đồ kết nối MC60:

18

Hình 4.4.2 Sơ đồ kết nối MC60

### 4.4.2. Khối cấp nguồn

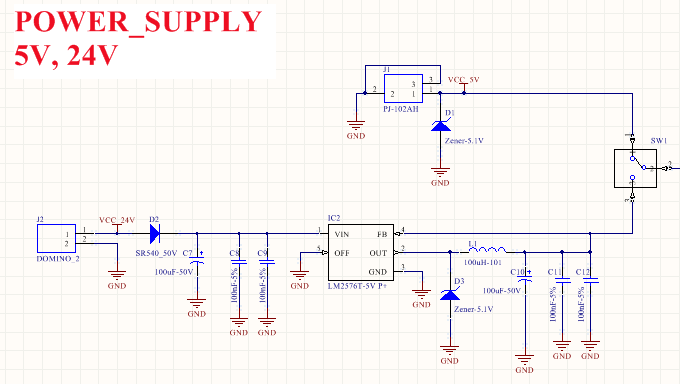
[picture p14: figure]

Hình 4.4.3 Đầu vào 5V sử dụng DC jack 3 chân

- Đầu vào 24V sử dụng Domino 2 chân
- LM2576-5V chuyển điện áp từ 24V sang 5V
- Diode D2 được sử dụng để ngăn dòng điện khi mắc ngược nguồn 24V
- Các tụ được đặt cạnh nguồn được sử dụng để lọc nguồn
- SW1 chọn nguồn cấp cho module

19

Hình 4.4.4 Khối cấp nguồn

- SW2 cho phép cấp nguồn cho module
- IC MIC29302 hạ điện áp 5V xuống còn 4V (VBAT)
- IC MIC29302 hạ điện áp 5V xuống còn 3.3V cấp cho phần GNSS
- Điện áp lấy ra từ chân OUT của MIC29302 được tính bằng công thức:

Hình 4.4.5 Lấy điện áp từ MIC29302

Với R1=75K, R2=43K, ta có:

Vout = 1.235. (1 +

75K
43K

) = 3.39 (V)

20

Hình 4.4.6 Sơ đồ VBAT

- Để hiệu suất nguồn tốt hơn, đặt tụ 100uF tantalum với ESR nhỏ (ESR=0,7Ω) và tụ caremic

100nF, 33pF,10pF gần chân VBAT.

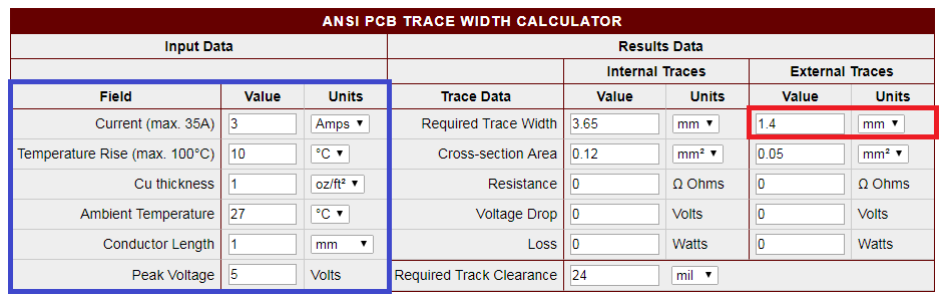
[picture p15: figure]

21

- Tính toán độ rộng Power trace với Subtrate FR4 và theo chuẩn IPC-2221A

Hình 4.4.7 Tính độ rộng Power Trace

- Từ kết quả của bảng trên, chọn độ rộng Power trace là 2mm. Đảm bảo khả năng chịu

dòng của Power trace và nhiệt độ tăng lên nhỏ hơn 100

- Power trace ngắn nhất có thể để giảm thiểu tối đa hao phí năng lượng trên power trace

### 4.4.3. Khối giao tiếp Audio

- Handset:
- MC60 giao tiếp với handset qua Audio Channel 1:

Hình 4.4.8 MC60 - Handset qua Audio Channel 1

- Mô tả các chân của Audio Channel 1:

Bảng 4.4.1 Mô tả chân Audio Channel 1

Tín hiệu | Mô tả
MICN | Ngõ vào Negative của Audio Channel 1
MICP | Ngõ vào Positive của Audio Channel 1
SPKP | Ngõ ra Positive của Audio Channel 1
SPKN | Ngõ ra Negative của Audio Channel 1
- Tụ 10pF, tụ 30pF được sử dụng để lọc nhiễu TDD.
- ESD9B5.0STG5 được sử dụng để chống ESD.

22

- Earphone:
- MC60 module giao tiếp với earphone qua Audio Channel 2 với sơ đồ mạch chi tiết:

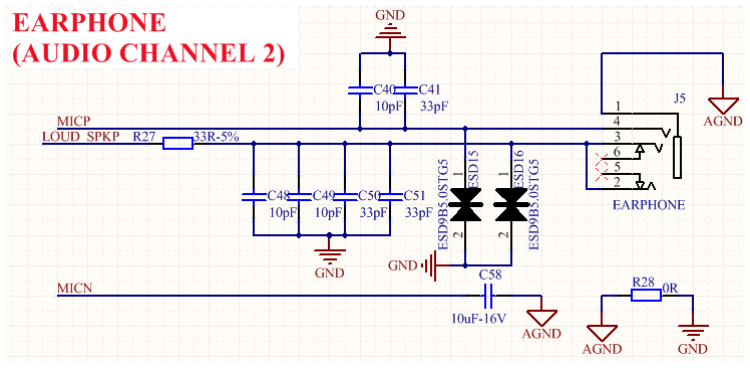
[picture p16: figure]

Hình 4.4.9 MC60 – earphone qua Audio Channel 2

- Mô tả chân của Audio Jack:

Bảng 4.4.2 Mô tả chân Audio Jack

Chân | Mô tả
AGND (1) | GND dành riêng cho audio
MICP (4) | Ngõ vào Positive của Audio Channel 2
SPKL (3) | Kênh bên trái của ngõ ra audio
SPKR (2) | Kênh bên phải của ngõ ra audio
(5) Not connected
(6) Not connected

### 4.4.4. Khối giao tiếp thẻ SIM

- Sơ đồ mạch chi tiết:

Hình 4.4.10 Sơ đồ mạch chi tiết SIM1

- Mô tả các chân của SIM1:

23

Bảng 4.4.3 Mô tả chân SIM1

Chân | Mô tả
GND | GND
VPP | Not connected
I/O | SIM1 card data I/O
CLK | SIM1 card clock
RST | SIM1 card reset
VCC | SIM1 power

Hình 4.4.11 Sơ đồ mạch chi tiết SIM2

- Mô tả các chân của SIM2:

Bảng 4.4.4 Mô tả chân SIM2

Chân | Mô tả
GND | GND
VPP | Not connected
I/O | SIM2 card data I/O
CLK | SIM2 card clock
RST | SIM2 card reset
VCC | SIM2 power
- Giá trị của C19, C20 nên nhỏ hơn 1uF
- ESD9B5.0STG5 được sử dụng để bảo vệ thẻ SIM chống lại ESD (hiện tượng phóng

điện do tĩnh điện.)

- Các tụ điện nên nhỏ hơn 50pF.
- Chân GND của SIM nên nối với chân GND của MC60 (chân 16).
- Điện trở 22 Ω được nối giữa SIM và module để chống lại EMI (nhiễu sóng điện từ) và

tăng cường bảo vệ khỏi ESD.
- Giữ cho thẻ SIM gần module nhất có thể. Giữ cho chiều dài trace nhỏ hơn 200mm.

### 4.4.5. Khối antenna

Module có 3 giao tiếp antenna được sử dụng cho GSM antenna, GNSS antenna and BT antenna.

- GSM antenna:

24

GSM antenna pad là chân RF_ANT (chân số 41) của MC60-OpenCPU

- Sơ đồ mạch chi tiết:

Hình 4.4.12 Sơ đồ mạch GSM antenna

- C31, C32, R12 là một mạch phối hợp trở kháng, dự trữ cho việc tối ưu hóa hiệu suất

truyền tín hiệu khi antenna thay đổi. Ở mặc định, R12 = 0Ω, C31, C32 không kết nối.

Trở kháng RF trace nên được điều chỉnh về 50Ω

- Để giảm tổn hao trên RF Trace và RF Antenna, chú ý khi thiết kế với những yêu cầu sau:
- Yêu cầu về Antenna Cable:

Bảng 4.4.5 Yêu cầu Antenna Cable

- Yêu cầu về Antenna:

Bảng 4.4.6 Yêu cầu thông số antenna

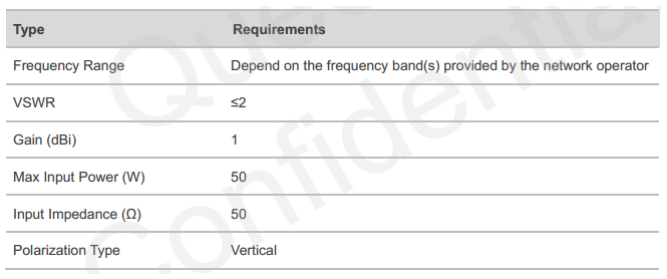
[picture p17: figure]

- Các dải tần:

25

Bảng 4.4.7 Các dải tần GSM

- GNSS Antenna: GNSS antenna pad là chân GNSS_ANT (chân số 15) của MC60-OpenCPU
- Module có thể được kết nối với antenna GPS/GLONASS chuyên dụng theo kiểu thụ động

hoặc chủ động để kết nối với tín hiệu GPS/GLONASS vệ tinh. Các thông số đối với antenna

GPS đươc thể hiện ở bảng dưới:

Bảng 4.4.8 Thông số đối với antenna GPS

Ở đây, ta sử dụng antenna chủ động, sơ đồ mạch chi tiết như hình:

Hình 4.4.13 Sơ đồ mạch GNSS Antenna

- C35, C36, R17 là mạch phối hợp trở kháng hình ‘Pi’, dự trữ cho việc phối hợp trở kháng

khi trở kháng đặc tính của antenna thay đổi. Ở mặc đinh, R17 = 0Ω, C35, C36 không

kết nối.

- Antenna chủ động được cấp nguồn từ GNSS_VCC (ở đây là nguồn 3.3V)

L2 được sử dụng để ngăn chặn tín hiệu RF rò rỉ sang GNSS_VCC. Giá trị của L2 không nhỏ

hơn 47nH. R2 có thể bảo vệ mạch trong trường hợp antenna bị nối đất

26

- Bluetooth antenna:
- Bluetooth antenna pad là chân BT_ANT (chân số 32) của MC60-OpenCPU
- Sơ đồ mạch chi tiết:

Hình 4.4.14 Sơ đồ mạch GSM antenna

- Mạch phối hợp trở kháng nên đặt gần antenna.
- Trở kháng RF trace nên điều chỉnh về giá trị 50Ω
- RF trace nên được giữ tránh xa các tín hiệu cao tần
- THIẾT KẾ PCB CHO RF TRACE

Những yếu tố ảnh hưởng đến trở kháng của RF trace bao gồm:

- Hằng số điện môi Er
- Độ dày phíp đồng H
- Độ rộng đường đồng W
- Bề dày lớp đồng T
- Ground S

Đối với Subtrate phổ biến thường gặp là FR4. Nên thiết kế theo các giá trị sau để đạt trở kháng

của RF trace là 50Ω, để tín hiệu truyền trên RF trace sẽ không bị phải xạ.

27

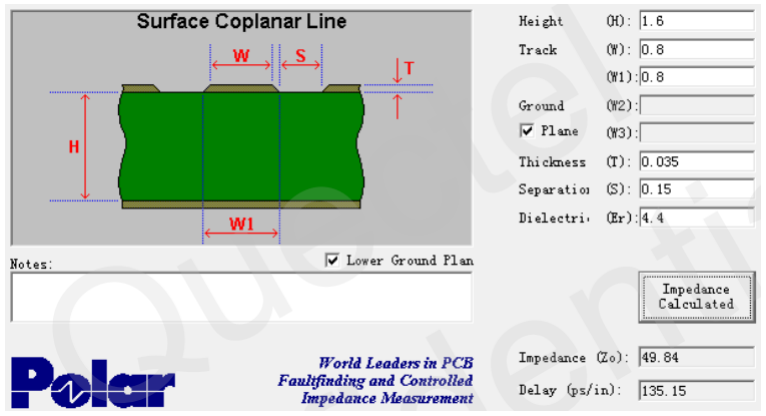
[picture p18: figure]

Hình 4.4.15 Thiết kế RF Trace 50Ω

- Điểm đặc biệt khi thiết PCB cho RF trace:
- Cần giữ cho giá trị của W và S luôn đảm chính xác nhất có thể trên suốt RF trace để trở

kháng đặc trưng được giữ đúng tại mọi điểm trên RF trace

- RF trace nên ngắn nhất có thể để suy hao tín hiệu là ít nhất
- Giữ một khoảng cách giữa Pad của tín hiệu và Ground.
- Đặt mạch phối hợp trở kháng “Pi” gần Pad antenna nhất có thể

### 4.4.6. Giao tiếp UART

- Sơ đồ mạch chi tiết:

Hình 4.4.16 Sơ đồ mạch chi tiết Main UART

28

- Mô tả chân của cổng DB9:

Bảng 4.4.9 Mô tả chân của cổng DB9

Chân | Mô tả
DCD (1) | Data carrier detection Cảm nhận sóng mang trên chân này và báo hiệu giữa 2 DCE
TXD (2) | Transmit data Truyền data
RXD (3) | Receive data Nhận data
DTR (4) | Data terminal ready Tín hiệu báo hiệu của DTE cho DCE biết DTE hoạt động.
GND (5) | Ground
(6) Không kết nối
RTS (7) | Request to send DTE báo cho DCE biết nó có thể nhận data
CTS (8) | Clear to send DCE báo cho DTE biết nó có thể nhận data
RI (9) | Ring indicator DCE báo cho DTE là đã nhận được tín hiệu chuông

Hình 4.4.17 Sơ đồ chân DB9

### 4.4.7. Giao tiếp với thẻ SD

- Module cung cấp một giao tiếp với thẻ SD, hỗ trợ nhiều loại bộ nhớ như Memory Stick,

SD/MCC Card, và T-Flash ( Micro SD) card. Các đặc điểm chính của giao tiếp SD:

- Chỉ hỗ trợ truyền nối tiếp 1 bit
- Không hỗ trợ giao tiếp SPI đối với thẻ SD
- Không hỗ trợ nhiều thẻ SD
- Tốc độ dữ liệu lên đến 48MHz ở chế độ truyền nối tiếp
- Hỗ trợ thẻ SD có bộ nhớ lên đến 32GB
- Người dùng có thể lưu trữ các thư mục có dung lượng lớn vào Micro-SD. Module cho phép

ghi và lưu trữ audio files, và cũng có thể phát audio files trong Micro-SD.

- Sơ đồ mạch chi tiết:

29

Hình 4.4.18 Sơ đồ mạch SD Card

- ESD9B5.0STG5 dùng để bảo vệ Micro-SD card khỏi ESD
- Mô tả chân của Micro-SD:

Bảng 4.4.10 Mô tả chân của Micro-SD

### 4.4.8. POWER LED và NETLIGHT LED, PWRKEY Button

- POWER LED

Hình 4.4.19 Sơ đồ mạch POWER LED

- PWRKEY Button
Chân | Mô tả
DATA2 (1) | Dữ liệu ra và tín hiệu vào của Micro-SD
DATA3 (2) | Dữ liệu ra và tín hiệu vào của Micro-SD
CMD/DI (3) | Tín hiệu lệnh của Micro-SD
VCC (4) | Nguồn cấp cho Micro-SD
CLK (5) | Tín hiệu Clock cho Micro-SD
GND (6) | GND
DATA0/DO (7) | Dữ liệu ra và tín hiệu vào của Micro-SD
DATA1 (8) | Dữ liệu ra và tín hiệu vào của Micro-SD

30

Hình 4.4.20 Sơ đồ mạch PWRKEY Button

- ESD9B5.0STGG5 được dùng để bảo vệ khỏi ESD, nên đặt gần nút nhấn

31

### 5. THIẾT KẾ VÀ THỰC HIỆN PHẦN MỀM

### 5.1. Phần mềm thiết bị giám sát (Tracker)

### 5.1.1. Phân tích

- Phần mềm thực hiện trình tự 4 công đoạn chính
- Kiểm tra các kết nối, thiết lập phần cứng của Host (lắp sim, đăng kí GSM, GPRS)
- Lấy dữ liệu GPS từ module GPS được tích hợp sẵn
- Lấy dữ liệu nhiệt độ, độ ẩm từ Slave thông qua Bluetooth
- Gửi toàn bộ dữ liệu thu thập được về web server

### 5.1.2. Yêu cầu đặt ra cho phần mềm

- Phần mềm thực hiện gửi dữ liệu về máy chủ dịch vụ web gồm các thông số (kinh độ, vĩ độ,

thời gian, ngày tháng năm, nhiệt độ, độ ẩm, mã ID thiết bị, mã ID gói dữ liệu, mã khóa)

thông qua phương thức HTTP POST.
- Giải thích các thông số:
- Kinh độ, vĩ độ : kiểu float
- Thời gian : định dạng hh:mm:ss
- Ngày tháng năm : định dạng yyyy/mm/dd
- Nhiệt độ : kiểu integer , đơn vị độ C
- Độ ẩm : kiểu integer, đơn vị %
- Mã ID thiết bị : kiểu integer, mỗi thiết bị có một mã cố định được khai báo sẵn.
- Mã ID gói dữ liệu : kiểu integer, mỗi một gói dữ liệu gửi lên web server sẽ có mã riêng.
- Mã khóa: định dạng true/false, kiểm tra trạng thái đóng hay mở cửa container. Nếu mã

khóa là false, chương trình sẽ gửi lại dữ liệu lên web server.

- Việc đọc và truyền dữ liệu cần được thực hiện trong thời gian ngắn, sau đó cần đặt hệ thống

ở chế độ sleep để tiết kiệm năng lượng.

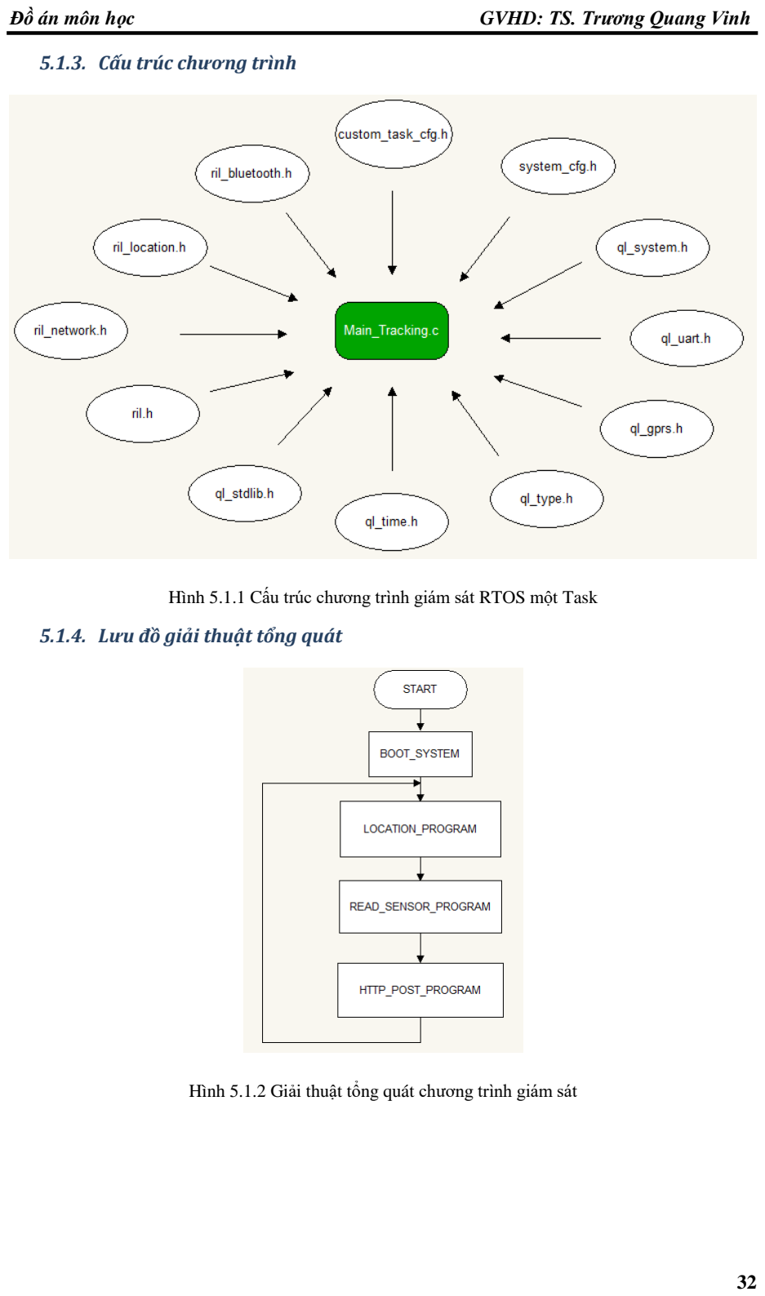
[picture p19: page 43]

32

### 5.1.3. Cấu trúc chương trình

Hình 5.1.1 Cấu trúc chương trình giám sát RTOS một Task

### 5.1.4. Lưu đồ giải thuật tổng quát

Hình 5.1.2 Giải thuật tổng quát chương trình giám sát

33

### 5.1.5. Lưu đồ giải thuật chi tiết

- BOOT_SYSTEM : Khi bắt đầu khởi động, chương trình báo về cho người dùng trạng thái

của module đã sẵn sàng hay chưa. Nếu xảy ra lỗi (chưa lắp sim, sim chưa đăng kí GPRS,

GSM, …) chương trình sẽ thông báo.

Hình 5.1.3 Giải thuật Boot System

- LOCATION_PROGRAM: Chương trình đọc dữ liệu GPS (kinh độ, vĩ độ, thời gian).

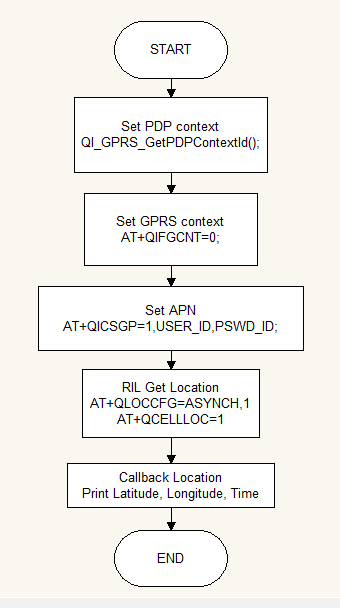
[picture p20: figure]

Hình 5.1.4 Giải thuật Location Program

34

- READ_SENSOR_PROGRAM : Host gửi yêu cầu cho Slave, yêu cầu Slave gửi về dữ liệu

(nhiệt độ, độ ẩm) trong container.

- Hình dưới đây mô tả sự thiết lập truyền nhận dữ liệu giữa Host và Slave qua Bluetooth.

Hình 5.1.5 Giải thuật đọc cảm biến

- Hình sau mô tả sự thiết lập chế độ truyền nhận Bluetooth của module MC60 (Host).

35

Hình 5.1.6 Giải thuật truyền nhận Bluetooth(Host)

- Hình sau mô tả sự thiết lập chế độ truyền nhận Bluetooth của module đọc nhiệt độ, độ

ẩm (Slave)

36

Hình 5.1.7 Giải thuật truyền nhận Bluetooth (Slave)

37

- HTTP_POST_PROGRAM : Hệ thống gửi toàn bộ dữ liệu cho máy chủ dịch vụ web thông

qua phương thức HTTP POST

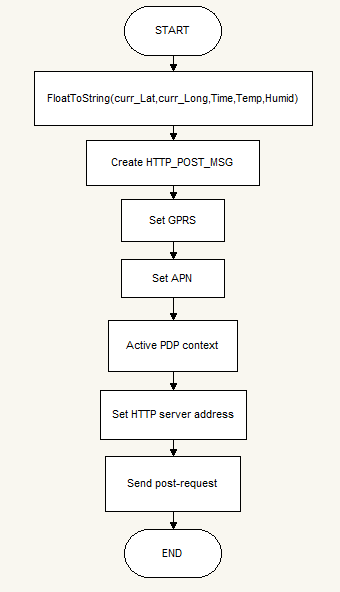
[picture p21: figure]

Hình 5.1.8 Giải thuật HTTP POST

38

### 5.2. Phần mềm web server

### 5.2.1. Yêu cầu đặt ra

- Phục vụ được nhiều người dùng truy cập cùng lúc
- Giao tiếp đồng thời được với nhiều thiết bị thu thập (tracker) thời gian thực
- Giao diện web đơn giản dễ sử dùng và bảo trì, dễ tái cấu trúc
- Cấu trúc database đơn giản, dễ truy cập

### 5.2.2. Phân tích

Web server thực hiện 2 chức năng chính: cung cấp dịch vụ giám sát thông qua giao diện web

và giao tiếp trao đổi dữ liệu với thiết bị giám sát.

### 5.2.2.1. Các tính năng của giao diện web

Bảng 5.2.1 Tính năng của giao diện web

Khách hàng | Quản trị viên | Chưa có tài khoản
1. Thủ tục đăng nhập/đăng xuất/quản lí thông tin tài khoản 2. Quản lí những dịch vụ của mình 3. Quản lí thiết bị của mình 4. Giám sát nhiệt đô – độ ẩm thông qua biểu đồ 5. Bảng thông tin nhiệt độ - độ ẩm, trạng thái khóa 6. Định vị thiết bị và vẽ đường đi trên google map 7. Cài đặt ngưỡng và thiết lập cảnh báo vượt ngưỡng nhiệt độ, độ ẩm 8. Cảnh báo mở khóa 9. Xem thông tin cảnh báo | 1. Đăng nhập/đăng xuất/quản lí thông tin tài khoản của QTV 2. Quản lí tài khoản khách hàng 3. Quản lí danh sách thiết bị 4. Quản lí các dịch vụ đã được khách hàng đăng kí | 1. Đăng kí tài khoản mới

### 5.2.2.2. Tính năng giao tiếp với thiết bị giám sát

Bảng 5.2.2 Tính năng giao tiếp với tracker

Thiết bị có trong danh sách | Thiết bị lạ
1. Lưu data vào CSDL 2. Xác nhận đã nhận gói tin | Phản hồi “forbidden, 403”

39

### 5.2.3. Thiết kế web server

### 5.2.3.1. Giới thiệu SailsJs và MVC

- SailsJS là một framework với mong muốn tạo ra một NodeJS framework "dễ sử dụng

và đầy đủ mọi thứ" như Ruby on Rails. Xây dựng bên trên ExpressJS, SailsJS tận dụng

được những điểm mạnh của framework này, đồng thời tích hợp thêm nhiều tiện ích khác

như:
- Socket.io giúp đồng bộ realtime dữ liệu giữa client và server, đây cũng là điểm

mạnh được đội ngũ phát triển SailsJS quảng bá nhiều nhất.

- ORM Waterline giúp bạn khai báo và quản lý database tốt hơn, đồng thời có thể

chuyển qua lại giữa những loại database khác nhau: MySQL, MongoDB, …

- Mô hình MVC
- Mô hình MVC:

Hình 5.2.1 Mô hình MVC và SailsJs

- M là Model: cấu trúc dữ liệu theo cách tin cậy và chuẩn bị dữ liệu theo lệnh của

controller.
- V là View: Hiển thị dữ liệu cho người dùng theo cách dễ hiểu dựa trên hành

động của người dùng.

- C là Controller: Nhận lệnh từ người dùng, gửi lệnh đến cho Model để cập nhập

dữ liệu, truyền lệnh đến View để cập nhập giao diện hiển thị.

40

### 5.2.3.2. View

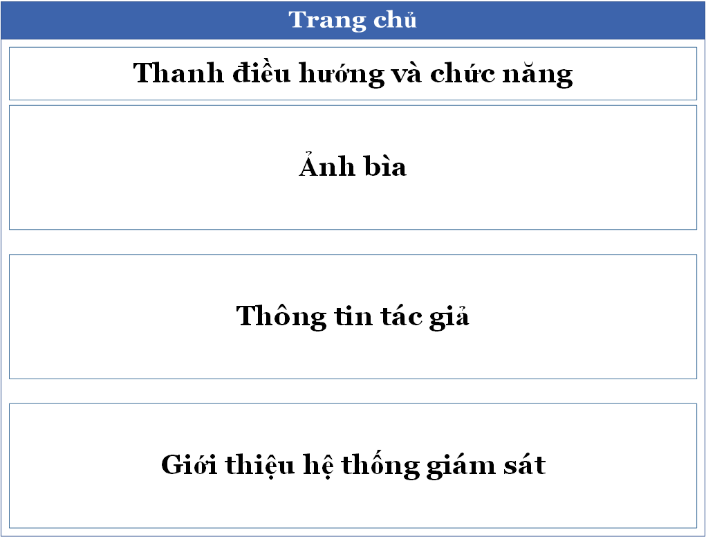
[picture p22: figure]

Hình 5.2.2 Giao diện trang chủ

Hình 5.2.3 Giao diện quản lí của khách hàng

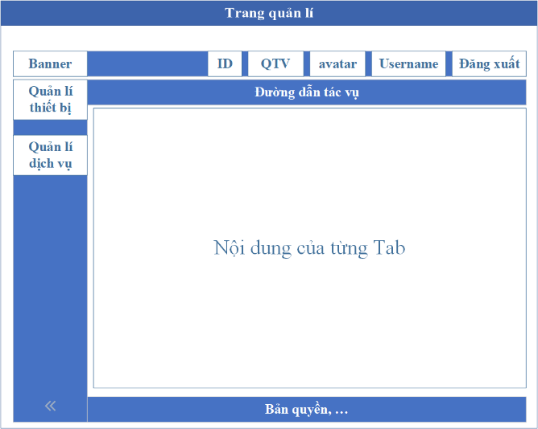
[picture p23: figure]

Hình 5.2.4 Giao diện quản lí của quản trị viên

41

### 5.2.3.3. Model

Hình 5.2.5 Cấu trúc CSDL và quan hệ giữa các trường

### 5.2.3.4. Controller

- Backend phục vụ dịch vụ web

Các giao thức mà thông qua đó người duyệt web gửi yêu cầu đến server thông qua giao diện

(view) chủ yếu là: GET, POST, PUT.

Bảng 5.2.3 API phục vụ dịch vụ web

Chức năng | APIs
Server-rendered HTML webpages | 'GET /': 'PageController.showHomePage', 'GET /dashboard': 'PageController.showDashboardPage', 'GET /signup': 'PageController.showSignupPage', 'GET /forgotPassword': 'PageController.showForgotPasswordPage', 'GET /tabview/user/map': 'PageController.showMapPage',
Khách hàng | 'PUT /user/login': 'UserController.login', 'PUT /user/remove-profile': 'UserController.removeProfile', 'POST /user/signup': 'UserController.signup',

42

| 'POST /logout': 'UserController.logout', 'GET /:username': 'PageController.showProfilePage',
Quản trị viên | 'GET /user/admin': 'UserController.adminUsers', 'PUT /user/update-admin/:id': 'UserController.updateAdmin', 'PUT /user/update-banned/:id': 'UserController.updateBanned', 'PUT /user/update-deleted/:id': 'UserController.updateDeleted', 'PUT /user/change-password': 'UserController.changePassword', 'PUT /user/update-gravatarUrl': 'UserController.updateGravatarUrl', 'POST /logout': 'UserController.logout', 'GET /profile/:username' : { controller: 'PageController', action: 'showProfilePage', skipAssets: true },
Thiết bị | 'GET /device/GetDevList': 'DeviceController.GetDevList', 'POST /device/AddDevice': 'DeviceController.AddDevice', 'GET /device/GetDevInfoByDevId/:DevID' : 'DeviceController.GetDevInfoByDevId', 'PUT /device/RemoveDevice' : 'DeviceController.RemoveDevice',
Dịch vụ | 'GET /service/GetServiceList': 'ServiceController.GetServiceList', 'GET /service/GetServiceDataByID/:DevId' : 'ServiceController.GetServiceDataByID', 'GET /service/GetHistoryList': 'ServiceController.GetHistoryList', 'POST /service/GetHistoryListByRenter_Email_ID': 'ServiceController.GetHistoryListByRenter_Email_ID', 'GET /service/GetHistoryListByDevID/:DevID' : 'ServiceController.GetHistoryListByDevID', 'POST /service/AddService': 'ServiceController.AddService', 'PUT /service/AdminUpdateValid: 'ServiceController. AdminUpdateValid,
Bản đồ | 'GET /data_collect/GetMapDataByID/:DevId': 'Data_collectController.GetMapDataByID',
Cảm biến | 'GET /data_collect/GetDevDataByID/:DevId':'Data_collectController.GetDevDataByID', 'POST /data_collect/PostDevDataByID': 'Data_collectController.PostDevDataByID',
Cảnh báo | 'GET /warning/GetWarningList' : 'WarningController.GetWarningList',
Ngưỡng | 'GET /threshold/GetThresholdList' : 'ThresholdController.GetThresholdList', 'PUT /threshold/UpdateThreshold' : 'ThresholdController.UpdateThreshold', 'PUT /threshold/RemoveThreshold' : 'ThresholdController.RemoveThreshold',

43

- Backend giao tiếp với tracker

Bảng 5.2.4 API phục vụ giao tiếp tracker

Chức năng | APIs
Nhận dữ liệu | 'POST /data_collect/collectData': 'Data_collectController.collectData'
Xác nhận đã nhận dữ liệu thành công/thất bại do trùng gói dữ liệu | return res.json(200, { okID: createdRecord.packetid }); return res.json(201, { Record already saved! });

Bảng 5.2.5 Cấu trúc gói dữ liệu tracker gửi đến server

Trường | packetid | devid | curr_Humid | curr_Temp | curr_Lat | curr_Long | timestamp | locked
Ý nghĩa | Mã gói | Mã thiết bị | Độ ẩm | Nhiệt độ | Vĩ độ | Kinh độ | Thời gian thu dữ liệu | Trạng thái khóa

Bảng 5.2.6 Cấu trúc gói JSON server trả lời tracker nếu nhận thành công

okID packetid

44

### 6. KẾT QUẢ THỰC HIỆN

### 6.1. Phần cứng

6.1.1. 3D
- Hình ảnh 3D của mạch trên Altium:
- Mặt trên:

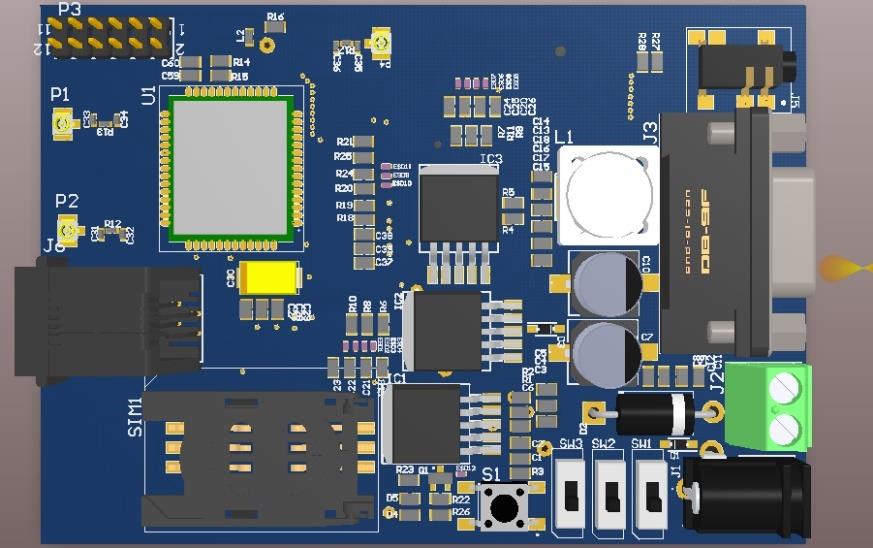
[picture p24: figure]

Hình 6.1.1 Ảnh 3D mặt trên

- Các RF connector được đặt cách xa nhau và được đặt gần các pin nhận tín hiệu của

MC60.
- Các tụ và ESD9B5.0STG5 được đặt gần các Port như Uart Port, Sim card, SD card, …
- Mặt dưới:

Hình 6.1.2 Ảnh 3D mặt dưới của mạch

45

### 6.1.2. LAYOUT

Hình 6.1.3 Ảnh Layout phần cứng

- Kích thước: 7x10cm
- RF trace có độ rộng 0.8mm, các RF trace đi cách xa nhau
- Power trace có độ rộng 2mm
- Power trace không đi qua SIM, Antenna, và độ dài ngắn nhất có thể.

46

### 6.2. Thiết bị giám sát

### 6.2.1. Thử nghiệm phần mềm giám sát trên KIT MC60 và KIT TM4C123GH6PM

### 6.2.1.1. Thu thập dữ liệu GPS

- Sử dụng phầm mềm Hercules hiển thị tọa độ

Hình 6.2.1 Kết quả dữ liệu GPS

- Bảng số liệu các địa điểm lấy mẫu:

Bảng 6.2.1 GPS mẫu

Địa điểm | Dữ liệu GPS
Kí túc xá Bách Khoa TP.HCM (497 Hòa Hảo,phường 7,quận 10,TP.HCM) | Lattitude : 10.761489 Longitude : 106.661667
Thư viện Trường Đại học Bách Khoa TP.HCM Cơ sở 1 (268 Lý Thường Kiệt, phường 14, quận 10, TP.HCM) | Lattitude : 10.7730498 Longitude : 106.660174
Thư viện Trường Đại học Bách Khoa TP.HCM Cơ sở 2 (phường Đông Hòa,huyện Dĩ An, tỉnh Bình Dương) | Lattitude : 10.880465 Longitude : 106.804364
- Phân tích, đánh giá kết quả:
- Dữ liệu thu được trùng khớp với dữ liệu kiểm tra từ GoogleMap.

### 6.2.1.2. Thu thập dữ liệu thời gian

- Sử dụng phầm mềm Hercules hiển thị thời gian

Hình 6.2.2 Kết quả dữ liệu thời gian

- Phân tích, đánh giá kết quả:
- Thời gian được lấy tại múi giờ 0 (giờ GMT)
- Dữ liệu thu được trùng khớp với dữ thiệu thực tế được kiểm tra từ đồng hồ.

47

### 6.2.1.3. Thu thập dữ liệu nhiệt độ, độ ẩm

- Sử dụng phầm mềm Hercules hiển thị quá trình kết nối, trao đổi dữ liệu qua Bluetooth giữa

Host và Slave.

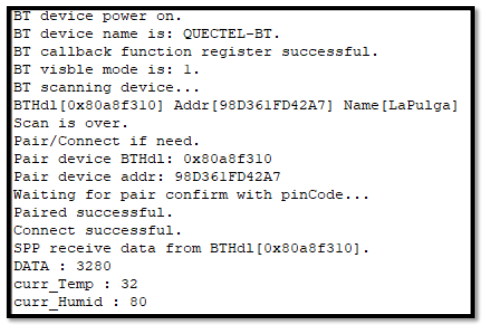
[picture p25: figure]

Hình 6.2.3 Kết quả đọc cảm biến nhiệt độ - độ ẩm

- Phân tích, đánh giá kết quả
- Dữ liệu nhiệt độ chênh lệch 1 độ C so với thực tế (đo bằng App trên Iphone 6)
- Dữ liệu độ ẩm chênh lệch 2% so với thực tế (đo bằng App trên Iphone 6)
- Đánh giá : dữ liệu nhiệt độ, độ ẩm đạt yêu cầu thiết kế.

### 6.2.1.4. Gửi dữ liệu lên web server

- Sử dụng phần mềm Hercules giám sát, hiển thị quá trình gửi dữ liệu.

48

Hình 6.2.4 Quá trình gửi dữ liệu

- Sử dụng phần mềm UntralVNC Viewer trên Window kiểm tra dữ liệu đã được gửi thành

công đến server:

Hình 6.2.5 Server đã nhận dữ liệu thành công

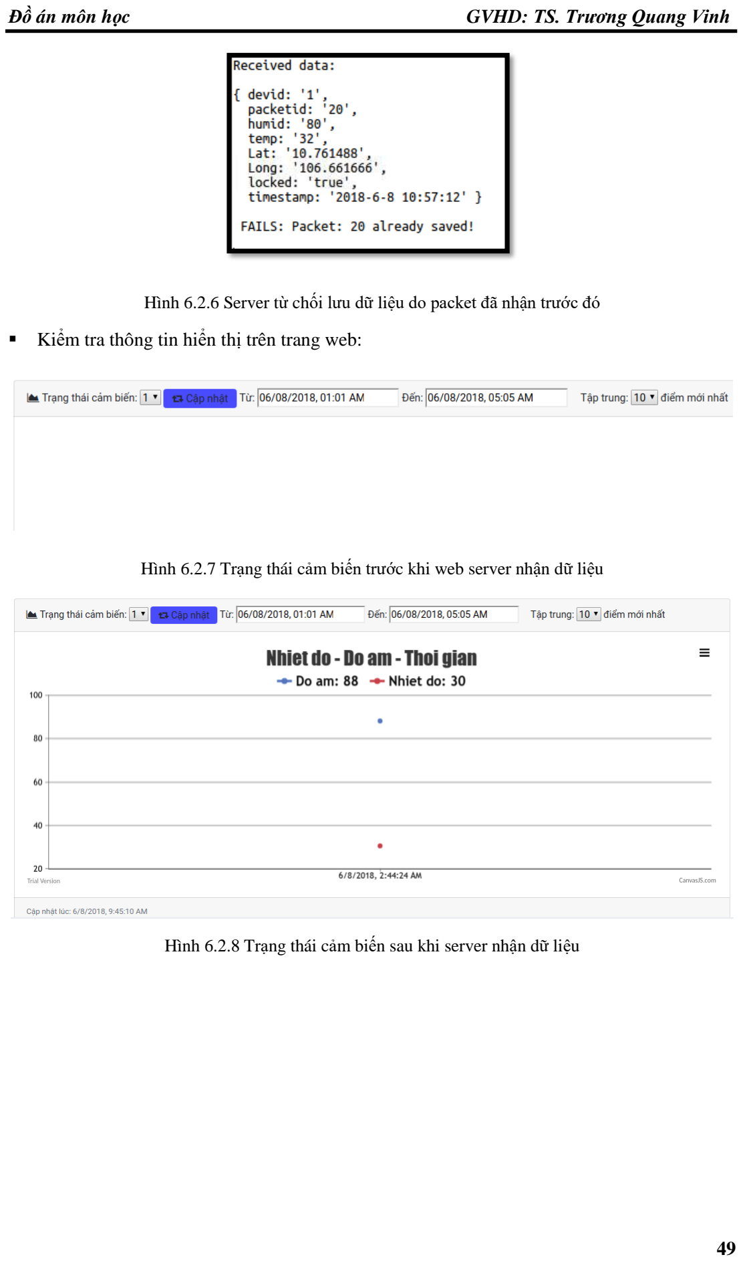
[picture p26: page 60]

49

Hình 6.2.6 Server từ chối lưu dữ liệu do packet đã nhận trước đó

- Kiểm tra thông tin hiển thị trên trang web:

Hình 6.2.7 Trạng thái cảm biến trước khi web server nhận dữ liệu

Hình 6.2.8 Trạng thái cảm biến sau khi server nhận dữ liệu

50

Hình 6.2.9 Hành trình trước khi server nhận dữ liệu

Hình 6.2.10 Hành trình sau khi server nhận dữ liệu

- Kết quả: phần mềm gửi đầy đủ dữ liệu ( mã thiết bị, mã gói tin, kinh độ, vĩ độ, thời gian,

nhiệt độ, độ ẩm, trạng thái mã khóa).

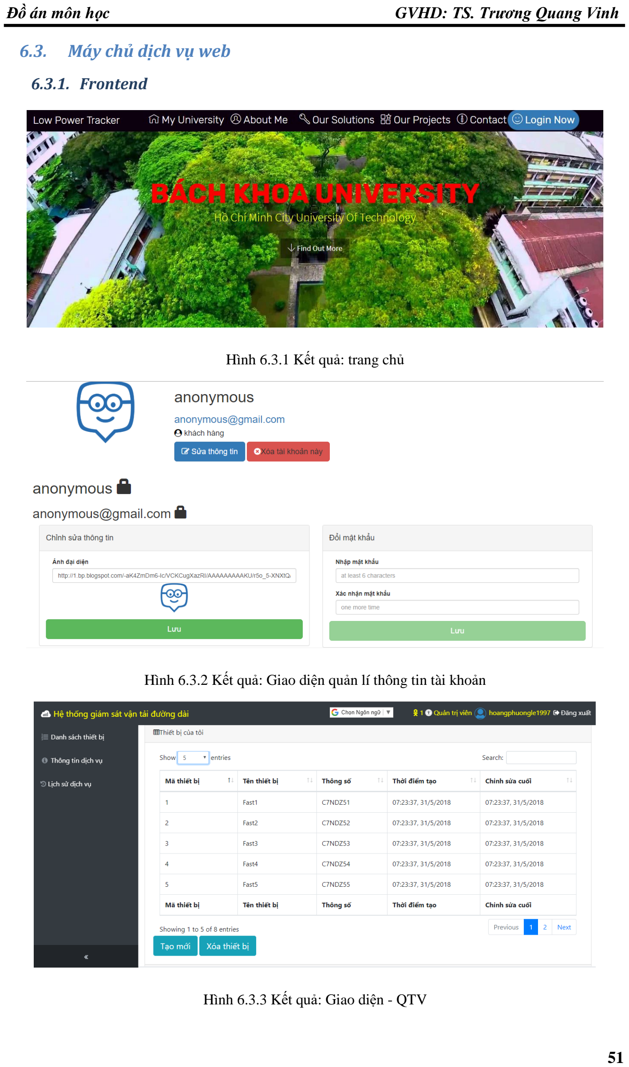
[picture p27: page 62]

51

### 6.3. Máy chủ dịch vụ web

### 6.3.1. Frontend

Hình 6.3.1 Kết quả: trang chủ

Hình 6.3.2 Kết quả: Giao diện quản lí thông tin tài khoản

Hình 6.3.3 Kết quả: Giao diện - QTV

52

Hình 6.3.4 Kết quả: Quản lí dịch vụ - QTV

Hình 6.3.5 Kết quả: Xem lịch sử DV - QTV

Hình 6.3.6 Kết quả: Trang quản lí - KH

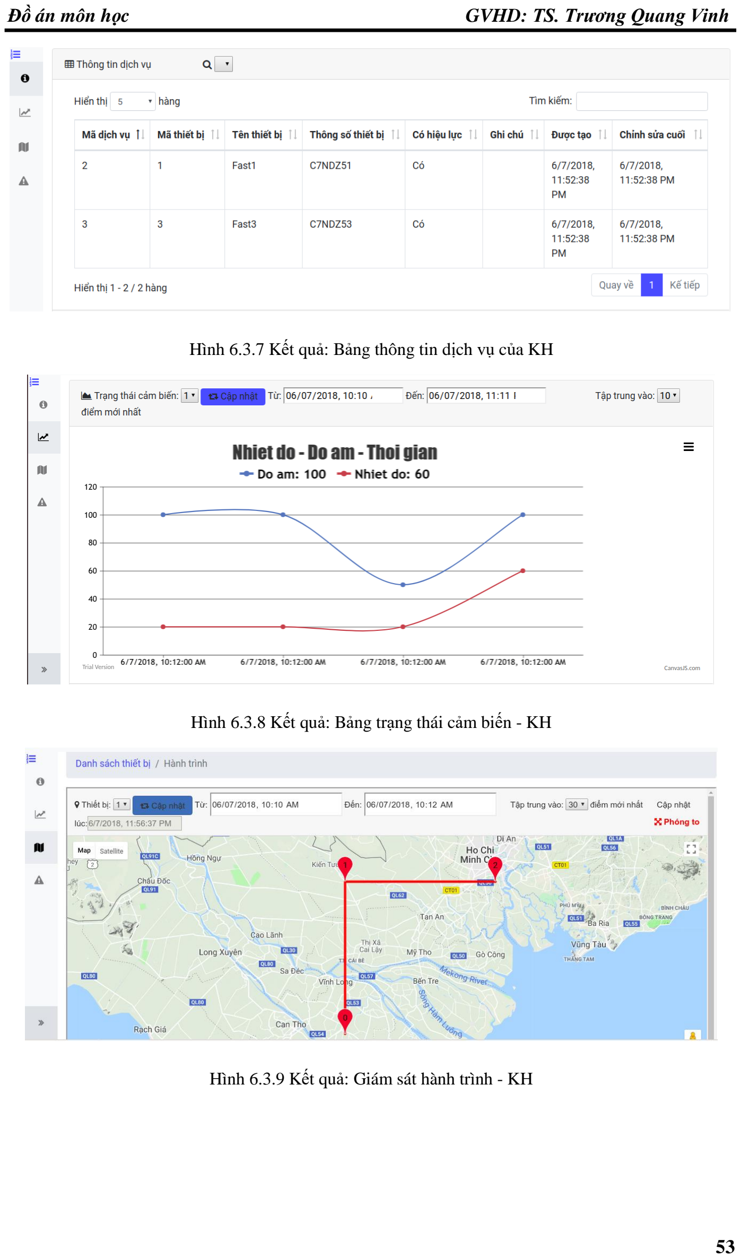
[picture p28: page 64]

53

Hình 6.3.7 Kết quả: Bảng thông tin dịch vụ của KH

Hình 6.3.8 Kết quả: Bảng trạng thái cảm biến - KH

Hình 6.3.9 Kết quả: Giám sát hành trình - KH

54

Hình 6.3.10 Kết quả: Ngưỡng - KH

Hình 6.3.11 Giao diện Cảnh báo -KH

- Để kiểm tra những yêu cầu từ người dùng thông qua giao diện đến máy chủ, chúng tôi sử

dụng đồng thời cả 2 phương pháp, sau đây là một phép kiểm tra điển hình:

Hình 6.3.12 Giao diện quản lí thiết vị - QTV

- Lưu thông tin tương tác trên console của máy chủ:

55

Hình 6.3.13 Màn hình console máy chủ

- Kiểm tra thông tin được hiển thị thông qua xem dữ liệu trên CSDL MySQL:

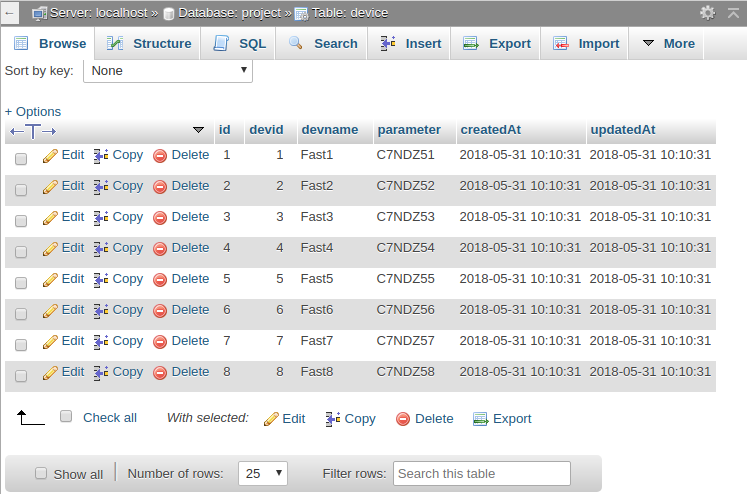
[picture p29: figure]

Hình 6.3.14 Thông tin trên MySQL

- Nhận thấy rằng thông tin được hiển thị trên giao diện người dùng hoàn toàn chính xác
- Để kiểm tra việc nhận được yêu cầu từ thiết bị giám sát, chúng tôi đã sử dụng công cụ mô

phỏng thiết bị giám sát, công cụ này có chức năng thực hiện một HTTP request giống như

thiết bị giám sát đến route được thiết kế sẵn trên máy chủ. Khi máy chủ nhận được yêu cầu

sẽ hiển thị thông tin nhận được ra console.

56

Hình 6.3.15 Mô phỏng gửi dữ liệu sử dụng Postman App

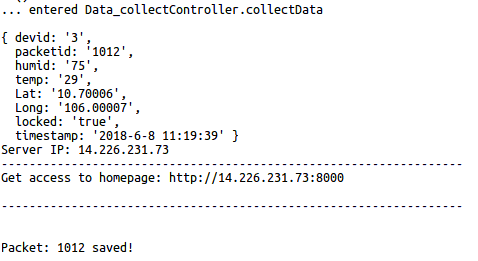
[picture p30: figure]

Hình 6.3.16 Yêu cầu từ Postman được ghi lại trên console

57

### 6.4. Đánh giá kết quả

### 6.4.1. Phần cứng

### 6.4.1.1. Khối nguồn

- Kết quả layout:

Hình 6.4.1 Khối nguồn (top)

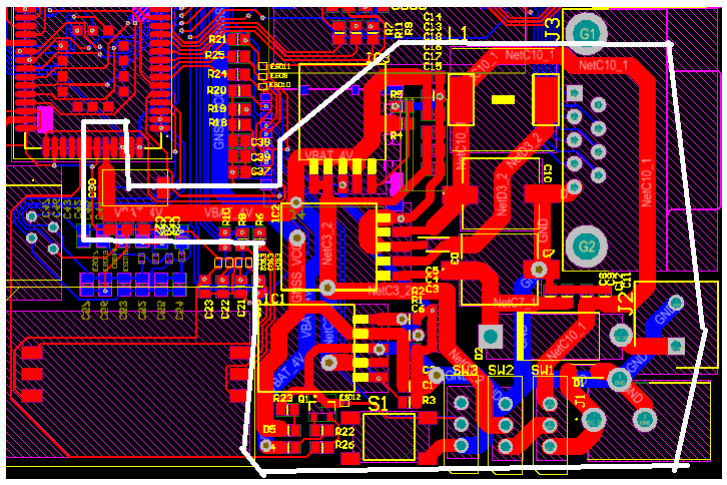
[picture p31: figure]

Hình 6.4.2 Khối nguồn (Bottom)

- Đánh giá kết quả:
- Power trace được thiết kế bề rộng đủ 2mm đảm bảo khả năng chịu dòng, chiều dài

Power trace ngắn nhất có thể nên hao phí trên đường truyền tải là ít nhất.

- Phần diện tích dành cho khối nguồn còn khá lớn.

58

### 6.4.1.2. Khối antenna

- Kết quả layout:

Hình 6.4.3 Khối antenna(top)

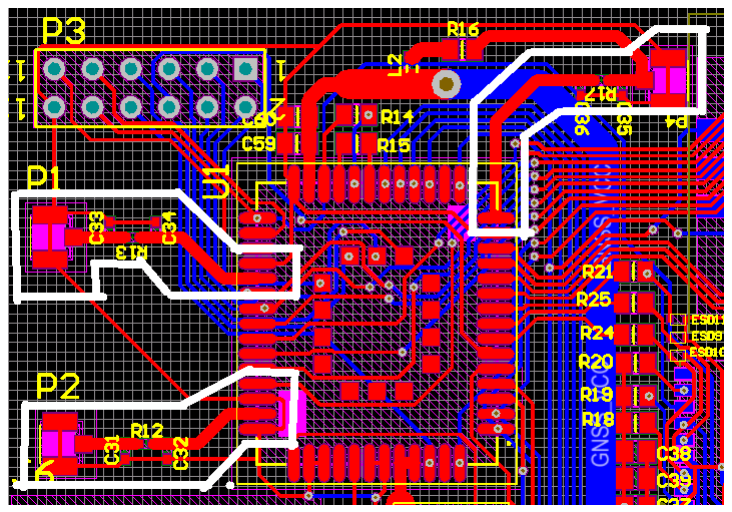
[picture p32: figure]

Hình 6.4.4 Khối antenna(bottom)

Hình 6.4.5 Đường dây truyền sóng

59

- Đánh giá kết quả:
- Vị trí đặt các RF connector cách xa nhau tránh được nhiễu qua lại giữa các tín hiệu.
- RF Trace được thiết gần đúng với các thông số đã tính toán với mong muốn đạt đươc

trở kháng 50Ω

- Mạch phối hợp hình “Pi” được đặt gần RF connector để dự trữ, phòng khi trở kháng của

antenna thay đổi.

### 6.4.2. Đánh giá tổng quát kết quả phần cứng

- Kích thước, giá thành đáp ứng yêu cầu đặt ra
- Khối nguồn có khả năng chịu dòng tốt, năng lượng hao phí trên đường tải không đáng

kể

- Các tín hiệu GSM, GNSS, Bluetooth đã được thiết kế tránh nhiễu, tránh phản xạ.
- Các linh kiện được bảo vệ khỏi ESD
- Chưa có phương án thiết kế khắc phục hiện tượng xả tải khi chuyển nguồn cấp 24V sang

5V. Chưa có test points để kiểm tra hoạt động của mạch khi cần

### 6.4.3. Thiết bị giám sát

- Thiết bị giám sát gửi đúng các dữ liệu sau:
- Mã thiết bị
- Kinh độ, vĩ độ
- Thời gian (múi giờ GMT 0)
- Nhiệt độ, độ ẩm
- Trạng thái khóa
- Trạng thái khóa: chưa thực tế hóa bằng phần cứng, đang giả sử khóa đóng/mở bằng phần

mềm

### 6.4.4. Máy chủ web

Máy chủ web đã được chúng tôi phát triển đầy đủ các tính năng như ban đầu đã đề ra. Giao diện

người dùng đẹp mắt, thích nghi. Đủ các chức năng cơ bản của một hệ thống giám sát. Biểu đồ

và bản đồ được hiển thị chính xác, thông tin cảnh báo đúng.

Backend máy chủ đáp ứng nhanh, đáp ứng được nhiều yêu cầu, Controller giao tiếp với Model

chính xác. Giao tiếp thiết bị giám sát chính xác và giao tiếp đồng thời được nhiều thiết bị.

60

### 6.4.5. Làm việc nhóm

Sau khoảng thời gian cùng nhau làm việc nhóm, 3 thành viên chúng tôi đã cùng nhau cố gắng

nổ lực để hoàn thành các nhiệm vụ được GVHD đề ra và những gì chúng tôi tự đặt mục tiêu

cho mình.

Làm việc nhóm khá hiệu quả, các bạn đã cùng nhau đóng góp ý kiến, giúp đõ nhau hoàn thành.

Các bạn biết cách phân công, sắp xếp thời gian để hoàn thành đúng tiến độ được giao.

Tuy nhiên, quá trình làm việc nhóm của chung tôi vẫn chưa thực sự hoàn hảo vì chúng tôi nhận

ra mình còn khá nhiều thiếu xót như tính đúng giờ, khả năng hoàn thành công việc của mỗi

người, khả năng cộng tác kế thừa và cùng hoàn thành hay độc lập riêng lẻ còn hạn chế.

Hi vọng trong những dự án sau, chúng tôi sẽ cố gắng khắc phục để cùng nhau tốt hơn.

61

### 7. KẾT LUẬN VÀ HƯỚNG PHÁT TRIỂN

### 7.1. Kết luận

Hệ thống giám sát vận tải đường dài là nhu cầu thiết yếu trong thời đại IoT và phát triển logistic

và giao thông vận tải, tuy nhiên việc thiết kế và hoàn thành một hệ thống chuẩn vẫn gặp rất

nhiều khó khăn.

Trong dự án này, chúng tôi đã đề xuất thiết kế một hệ thống giám sát vận tải đường dài tiết kiệm

năng lượng có tính ứng dụng thực tế cao sử dụng kết hợp mạng 2G/3G. Phần cứng được thiết

kế tối ưu hóa chức năng và tiết kiệm năng lượng. Giải thuật ứng dụng trên thiết bị giám sát đơn

giản, có khả năng tối ưu. Máy chủ web được xây dựng đơn giản, dễ bảo trì, tái cấu trúc và phát

triển. dịch vụ web được thiết với giao diện thích nghi, có thể sử dụng trên nhiều nền tảng hệ

điều hành, thiết bị với kích thước, độ phân giải khác nhau. Máy chủ web có thể chạy trên một

máy tính phần ứng nhẹ, có thể là Raspberry, thuận tiện cho khách hàng vừa và nhỏ có thể tự sở

hữu riêng cho mình một máy chủ, tiết kiệm chi phí thuê máy chủ.

Tuy nhiên, hệ thống này vẫn có một số khuyết điểm. Chức năng giám sát thông qua giao diện

ít, chưa thực sự thời gian thực. Phần cứng thiết kế chưa thực sự hoàn hảo về mặt năng lượng và

kích thước. Khả năng thu sóng GSM bị ảnh hưởng đáng kể khi mạch được đóng hộp kín. Giải

thuật giám sát chưa thực sự tối ưu, chưa phát triển tính năng sleep, việc thu thập dữ liệu còn

nhiều khuyết điểm.

Trong dự án này, chúng tôi cơ bản đã hoàn thành những mục tiêu đặt ra ban đầu.

### 7.2. Hướng phát triển

Mục tiêu phát triển chính của đề tài là có thể khắc phục những hạn chế đưa ra, chủ yếu trọng

tâm vào thiết kế phần cứng và tối ưu hóa giải thuật. Ứng dụng thêm những công cụ nâng cao

giúp tăng khả năng thời gian thực của máy chủ web.

Ứng dụng hệ thống giám sát vận tải này có thể được mở rộng thêm nhiều tính năng như dự đoán

đường đi, phát hiện sai hành trình và kết hợp với nhiều dự án IoT khác, …

Giải thuật phần mềm giám sát cần được cải thiện nâng cao hơn nữa như chế độ deep sleep, gửi

dữ liệu chọn lọc, giải thuật tiết kiệm năng lượng, lưu dữ liệu vào thẻ nhớ, …

Phần cứng thiết bị giám sát có thể tối ưu năng lượng hơn nữa, tích hợp module quản lí năng

lượng, nâng cao dung lượng pin, sử dụng linh kiện kích thước nhỏ hơn và chất lượng tốt hơn, ...

62

### 8. TÀI LIỆU THAM KHẢO

[1] https://sailsjs.com/
[2] https://nodejs.org/en/
[3] https://angularjs.org/
[4] https://getbootstrap.com/
[5] https://www.mysql.com/
[6] Quectel Wireless Solutions Co,"Quectel_GSM_ATC_Application_V1.0.pdf”,

www.quectel.com

[7] Quectel Wireless Solutions Co, “

Quectel_GSM_BT_Application_Note_V1.0.pdf”, www.quectel.com

[8] Quectel Wireless Solutions Co,

“Quectel_GSM_HTTP_AT_Commands_Manual_V1.0.pdf”, ww.quectel.com

[9] https://vi.wikipedia.org/wiki/Hệ_thống_Định_vị_Toàn_cầu
[10] https://vi.wikipedia.org/wiki/Bluetooth
[11] https://akizukidenshi.com/download/ds/aosong/DHT11.pdf
[12] https://www.creative-tim.com/?affiliate_id=101249

63

### 9. PHỤ LỤC

### 9.1. Code web server và thiết bị giám sát

https://github.com/LeVanHoangPhuong/Low-Power-Transportation-Monitoring-System.git

### 9.2. Danh sách linh kiện trong bản vẽ

Comment | Designator | Description | Footprint | Quant ity | Unit Price (VND ) | Price(V ND)
MC60 | MC60 | MC60 Quectel OpenMCU | | 1 | 4362 32 | 436232
MIC29032WU | IC1,IC3 | LDO Voltage Regulators | TO263-5 | 2 | 9000 | 18000
LM2576T-5V | IC2 | Step−Down Switching Regulator | TO263-5 | 1 | 1200 0 | 12000
MAIN-UART | J3 | Uart_Port | DB9 | 1 | 3000 | 3000
RF-Connector-Antenna | P2 | RF antenna | IPX SMD PCB Plug | 1 | 2000 | 2000
BT-Connector-Antenna | P1 | Bluetooth Antenna | IPX SMD PCB Plug | 1 | 2000 | 2000
GNSS-Connector-Antenna | P4 | GPS Antenna | IPX SMD PCB Plug | 1 | 2000 | 2000
GPS Antennna | | | | 1 | 7000 0 | 70000
Bluetooth Antenna | | | | 1 | 5000 0 | 50000
GSM antenna | | | | 1 | 3000 0 | 30000
0R-5% | R12,R13,R14 ,R15, R17,R28 | Resistor 0 ohm - 5% SMD | R0805 | 5 | 40 | 200
10R | R16 | Resistor 10 ohm - 5% SMD | R0805 | 1 | 40 | 40
470R | R23 | Resistor 470 ohm - 5% SMD | R0805 | 1 | 40 | 40
33R-5% | R21,R24,R25 ,R27 | Resistor 33 ohm - 5% SMD | R0805 | 4 | 40 | 160
47K-5% | R3,R18,R19, R20 | Resistor 47K ohm - 5% SMD | R0805 | 4 | 40 | 160
22R-5% | R6,R7,R8,R9, R10, R11 | Resistor 22 ohm - 5% SMD | R0805 | 6 | 40 | 240
120K-5% | R4 | Resistor 120K ohm - 5% | R0805 | 1 | 40 | 40
51K-5% | R5 | Resistor 51K ohm - 5% | R0805 | 1 | 40 | 40
43K-5% | R2 | Resistor 43K ohm - 5% | R0805 | 1 | 40 | 40
75K-5% | R1 | Resistor 75K ohm - 5% | R0805 | 1 | 40 | 40
1K-5% | R22,R26 | Resistor 1K ohm - 5% | R0805 | 2 | 40 | 80

64

100nF-5% | C5,C8,C9,C1 1,C12, C17,C19,C20 ,C27, C38,C59,C60 | CAP CER 100nF 50V 5% 0805 | C0805 | 12 | 700 | 8400
33pF-5% | C21,C22,C23 ,C24, C25,C26,C28 ,C39, C41,C43,C45 ,C47, C50,C51,C53 ,C55, C57 | CAP CER 33pF 50V 5% 0805 | C0805 | 17 | 350 | 5950
10pF | C29,C42,C44 ,C46, C52,C54,C56 ,C40, C48,C49 | CAP CER 10pF 50V 10% 0805 | C0805 | 10 | 350 | 3500
4.7uF-50V | C3,C37,C15 | CAP CER 4.7uF - 50V 0805 | C0805 | 3 | 550 | 1650
15pF-5%-50V | C2,C14 | CAP 15pF - 5% - 50V 0805 | C0805 | 2 | 350 | 700
75pF-5%-50V | C1,C13 | CAP 75pF - 5% - 50V 0805 | C0805 | 2 | 350 | 700
10uF-16V | C4,C6,C16,C 18, C58 | CAP CER 10uF 16V 0805 | C0805 | 5 | 1300 | 6500
100uF | C30 | CAP TANTALUM 100uF | SMD7403 | 1 | 5500 | 5500
100uF-50V | C7,C10 | CAP ALUM 100uF - 50V | 8x10mm | 2 | 3000 | 6000
2SC1815 | Q1,Q2,Q3 | 50V 150mA NPN SMD Transistor | SOT23_L | 3 | 500 | 1500
| | | | | | 0
47nH | L2 | Inductor 47nH | Inductor_06 03 | 1 | 1000 | 1000
100uH-101 | L1 | Inductor 100uH | 4x4x1.6mm | 1 | 3000 | 3000
SR540_50V | D2 | Diode 40V 5A | DO-201AD | 1 | 2500 | 2500
Zenner-5.1V | D1,D3 | Zenner - 5.1V SMD | SOD-123 | 2 | 300 | 600
ESD9B5.0STG5 | ESD1 -ESD19 | TVS DIODE 5VWM SOD923 | SOD923 | 19 | 600 | 11400
LED-G | D11,D12 | Led Green Smd 0603 | LED0603-G | 2 | 800 | 1600
BUTTON_SMD | S1 | Button Smd 4_Pins | 1 | 500 | 500
SWITCH | SW1,SW2,S W3 | Slide Switch 3 Pin | 3
HANDSETCON | J6 | RJ11 Socket 4 Positions -4 Contracts | 1 | 3000 | 3000

65

Jack audio SMD | J5 | Jack audio 2.5mm | 1 | 2000 | 2000
Jack DC | J1 | Jack DC | 1 | 1000 | 1000
Domino | J2 | | 1 | 1500 | 1500
SIM | SIM1, SIM2 | Sim card holder | 2 | 6000 | 12000
Micro SD Card | J4 | Micro SD Card Socket | 1 | 3000 | 3000
| | | | TOT AL | 709812

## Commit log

2018-06-16 Stable Version
    [Schematic_1.SchDoc, Schematic_2.SchDoc, Schematic_3.SchDoc]
2019-06-22 continue to developing
    [Schematic_1.SchDoc, Schematic_2.SchDoc, Schematic_3.SchDoc]
